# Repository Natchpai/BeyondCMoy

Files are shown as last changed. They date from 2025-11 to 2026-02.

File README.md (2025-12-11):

# BeyondCMoy

**Headphone Amplifier**

> Upgrade NORMAL Headphone Amplifier that my old classwork to something new.

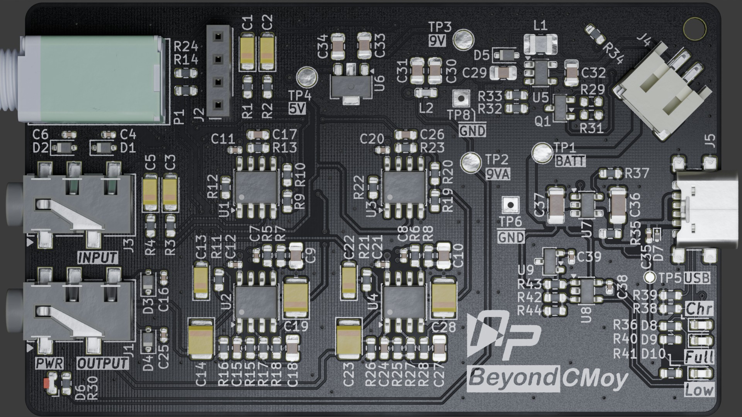
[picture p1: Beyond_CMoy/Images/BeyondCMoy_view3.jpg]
3D


## ✨ Features
- **Inputs:** Bluetooth and 3.5mm Aux jack
- **Battery:** Lithium polymer
- **Charging:** Via USB-C

## 📄 License

This project is licensed under the MIT License. See the [LICENSE](LICENSE) file for details.

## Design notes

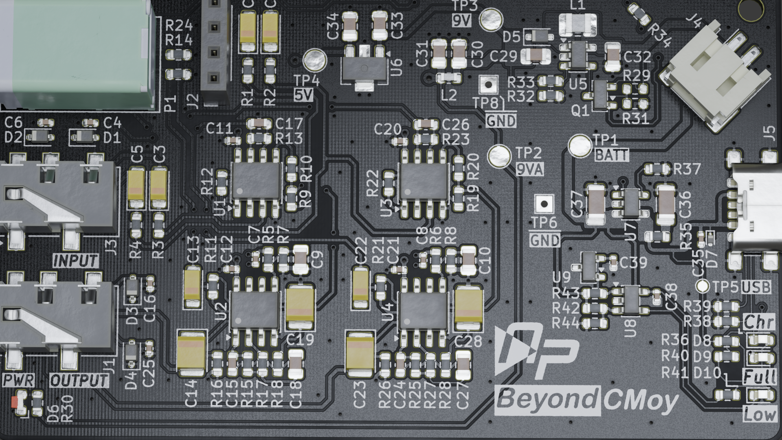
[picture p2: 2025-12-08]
Beyond_CMoy/Images/BeyondCMoy_view2.png

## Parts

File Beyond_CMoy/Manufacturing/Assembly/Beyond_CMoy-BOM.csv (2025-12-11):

# | Reference | Qty | Value | DNP | Exclude from BOM | Exclude from Board | Footprint | Manufacturer | Mf. Part Number | Datasheet | Description
1 | C1,C2,C3,C5,C13,C22 | 6 | 1u |  |  |  | Capacitor_Tantalum_SMD:CP_EIA-3216-18_Kemet-A | KYOCERA AVX | TAJA105M016RNJ |  | Tantalum Chip Capacitors 1μF/16Vdc, ±20%
2 | C14,C23 | 2 | 47u |  |  |  | Capacitor_Tantalum_SMD:CP_EIA-3528-21_Kemet-B | KYOCERA AVX | TAJB476K010RNJ | ~ | Tantalum Chip Capacitors 47μF/10Vdc, ±10%
3 | C15,C17,C24,C26 | 4 | 1n |  |  |  | Capacitor_SMD:C_0603_1608Metric | murata | GRM1885C2A102JA01J | ~ | 1nF/100Vdc, ±5%, C0G(NP0)
4 | C18,C27 | 2 | 0.22u |  |  |  | 0_Devices:0_C_0805_Edited | murata | GRM188R71E224KA88D | ~ | 0.22μF/25Vdc, ±10%, C0G(NP0)
5 | C19,C28 | 2 | 4.7u |  |  |  | Capacitor_Tantalum_SMD:CP_EIA-3528-21_Kemet-B | KYOCERA AVX | TAJB475K016RNJ |  | Tantalum Chip Capacitors 4.7μF/16Vdc, ±10%
6 | C36,C37 | 2 | 10u |  |  |  | Capacitor_SMD:C_1206_3216Metric | SAMSUNG | CL31A106KBHNNNE | ~ | Multilayer Ceramic Chip Cap, 10μF/50Vdc, ±10%, X5R
7 | C4,C6,C16,C25,C35 | 5 | 33p |  |  |  | Capacitor_SMD:C_0402_1005Metric | KYOCERA AVX | 04025A330JAT2A | ~ | 33pF/50Vdc ±5%, C0G(NP0)
8 | C7,C8,C11,C12,C20,C21,C38,C39 | 8 | 0.1u |  |  |  | Capacitor_SMD:C_0402_1005Metric | murata | GRM155R71H104KE14D | ~ | 0.1μF/50Vdc, ±10%, X7R
9 | C9,C10,C29,C30,C31,C32,C33,C34 | 8 | 1u |  |  |  | 0_Devices:0_C_0805_Edited | SAMSUNG | CL21B105KBFNNNE | ~ | 1μF/50Vdc, ±10%, X7R
10 | D5 | 1 | RB551VM-30 |  |  |  | Diode_SMD:D_SOD-323F | ROHM | RB551VM-30TE-17 | ~ | Schottky Barrier Single Diode 30V/500mA
11 | D6 | 1 | GREEN |  |  |  | LED_SMD:LED_Kingbright_APA1606_1.6x0.6mm_Horizontal | LITE-ON | LTST-S270KGKT | ~ | Light emitting diode
12 | D7 | 1 | ESD9L5.0ST5G |  |  |  | Diode_SMD:D_SOD-923 | ONSEMI | ESD9L5.0ST5G |  | ESD Protection Diode
13 | D8 | 1 | ORANGE |  |  |  | LED_SMD:LED_0603_1608Metric | ROHM | SML-D12D8WT86R | ~ | Light emitting diode
14 | D9 | 1 | GREEN |  |  |  | LED_SMD:LED_0603_1608Metric | LITE-ON | LTST-C191TGKT | ~ | Light emitting diode
15 | D10 | 1 | RED |  |  |  | LED_SMD:LED_0603_1608Metric | LITE-ON | LTST-C191KRKT | ~ | Super Thin Chip LED, Red Color
16 | D1,D2,D3,D4 | 4 | PESD12VL1BA |  |  |  | Diode_SMD:D_SOD-323 | NXP | PESD12VL1BA |  | ESD protection diode, 200W,Breakdown Voltage 15.9V
17 | J2 | 1 | Conn_01x04_Socket |  |  |  | Connector_PinSocket_2.54mm:PinSocket_1x04_P2.54mm_Vertical | - | - | ~ | 1x04 Female PinSocket
18 | J4 | 1 | Conn_01x02_MountingPin |  |  |  | Connector_JST:JST_PH_S2B-PH-SM4-TB_1x02-1MP_P2.00mm_Horizontal | JST | S2B-PH-SM4-TB | ~ | 1x02 JST-PH Connector
19 | J5 | 1 | USB_C_Receptacle_PowerOnly_6P |  |  |  | Connector_USB:USB_C_Receptacle_GCT_USB4135-GF-A_6P_TopMnt_Horizontal | SZGOZIE | TYPEC6P019 | https://www.usb.org/sites/default/files/documents/usb_type-c.zip | USB Power-Only 6P Type-C Receptacle connector
20 | J1,J3 | 2 | PJ-327F |  |  |  | 0_AudioConnectors:PJ-327F_SMD | - | PJ-327F | kicad-embed://C128989-PJ-327F.pdf | Auido Jack
21 | L1 | 1 | 10u |  |  |  | 0_Devices:0_L_1008_Edited | murata | DFE252010F-100M=P2 | ~ | Chip Metal Alloy Inductor 10μH ±20%
22 | L2 | 1 | 56n |  |  |  | Inductor_SMD:L_0603_1608Metric | murata | LQW18AN56NG00D | ~ | RF Inductor (Chip Coil), 56nH ±2%, 360mA
23 | P1 | 1 | 10k |  |  |  | 0_Potentiometer:0_RK097GS_Dual_Horizontal_Switch | - | RK097GS |  | 8-Pin Potentiometer 2 Gangs and Switch
24 | Q1 | 1 | MMBT3906 |  |  |  | Package_TO_SOT_SMD:SOT-23 | DIOTEC | MMBT3906 | https://www.onsemi.com/pdf/datasheet/pzt3906-d.pdf | -0.2A Ic, -40V Vce, Small Signal PNP Transistor, SOT-23
25 | R29 | 1 | 0 | DNP |  |  | Resistor_SMD:R_0603_1608Metric | ROYALOHM | 0603WAF0000T5E | ~ | Resistor
26 | R31 | 1 | 10k | DNP |  |  | Resistor_SMD:R_0603_1608Metric | ROYALOHM | 0603WAF1002T5E | ~ | Resistor
27 | R35 | 1 | 1 |  |  |  | Resistor_SMD:R_0603_1608Metric | ROYALOHM | 0603WAF100KT5E | ~ | Resistor
28 | R1,R2,R3,R4,R32,R43 | 6 | 10k |  |  |  | Resistor_SMD:R_0603_1608Metric | ROYALOHM | 0603WAF1002T5E | ~ | Resistor
29 | R12,R16,R22,R26 | 4 | 1k |  |  |  | Resistor_SMD:R_0603_1608Metric | ROHM | MCR03ERTF1001 | ~ | Resistor
30 | R13,R14,R18,R23,R24,R28,R36,R40,R41 | 9 | 2k |  |  |  | Resistor_SMD:R_0603_1608Metric | ROYALOHM | 0603WAF2001T5E | ~ | Resistor
31 | R15,R17,R25,R27,R30,R34,R37,R38,R39 | 9 | 5.1k |  |  |  | Resistor_SMD:R_0603_1608Metric | ROYALOHM | 0603WAF5101T5E | ~ | Resistor
32 | R33,R44 | 2 | 62k |  |  |  | Resistor_SMD:R_0603_1608Metric | ROYALOHM | 0603WAF6202T5E | ~ | Resistor
33 | R5,R6,R7,R8,R9,R10,R11,R19,R20,R21,R42 | 11 | 100k |  |  |  | Resistor_SMD:R_0603_1608Metric | ROYALOHM | 0603WAF1003T5E | ~ | Resistor
34 | TP1 | 1 | +BATT |  | Excluded from BOM |  | TestPoint:TestPoint_Pad_D2.0mm |  |  | ~ | test point
35 | TP2 | 1 | +9VA |  | Excluded from BOM |  | TestPoint:TestPoint_Pad_D2.0mm |  |  | ~ | test point
36 | TP3 | 1 | +9V |  | Excluded from BOM |  | TestPoint:TestPoint_Pad_D2.0mm |  |  | ~ | test point
37 | TP4 | 1 | +5V |  | Excluded from BOM |  | TestPoint:TestPoint_Pad_D2.0mm |  |  | ~ | test point
38 | TP5 | 1 | BUS |  | Excluded from BOM |  | TestPoint:TestPoint_Pad_D1.0mm |  |  | ~ | test point
39 | TP6,TP8 | 2 | GND |  | Excluded from BOM |  | TestPoint:TestPoint_THTPad_1.5x1.5mm_Drill0.7mm |  |  | ~ | test point
40 | U5 | 1 | AP3012 |  |  |  | Package_TO_SOT_SMD:SOT-23-5 | DIODES | AP3012KTR-E1 | https://www.diodes.com/assets/Datasheets/AP3012.pdf | 500mA, Adjustable Step-Up Voltage Regulator, 1.5MHz Frequency, SOT-23-5
41 | U6 | 1 | BD50FA1FP3 |  |  |  | Package_TO_SOT_SMD:SOT-89-3 | ROHM | BD50FA1FP3-ZTL | https://fscdn.rohm.com/en/products/databook/datasheet/ic/power/linear_regulator/bdxxfa1fp3-e.pdf | LDO Regulator Fixed Output 5V/100mA
42 | U7 | 1 | LP4054HB5F |  |  |  | Package_TO_SOT_SMD:SOT-23-5 | LPS | LP4054H | https://lcsc.com/product-detail/PMIC-Battery-Management_LOWPOWER-LP4054HB5F_C517187.html | 600mA Standalone Linear Li-ion Battery Charger
43 | U8 | 1 | BA8391G-TR |  |  |  | Package_TO_SOT_SMD:SOT-23-5 | ROHM | BA8391G-TR |  | Ground Sense Comparator,Open Collector
44 | U9 | 1 | TL432ASF |  |  |  | Package_TO_SOT_SMD:SOT-23 | HTC | TL432ASF | http://www.ti.com/lit/ds/symlink/tl431.pdf | Shunt Regulator, SOT-23
45 | U1,U2,U3,U4 | 4 | NE5532 |  |  |  | Package_SO:SOIC-8_3.9x4.9mm_P1.27mm | - | NE5532 | http://www.ti.com/lit/ds/symlink/ne5532.pdf | Dual Low-Noise Operational Amplifiers, DIP-8/SOIC-8

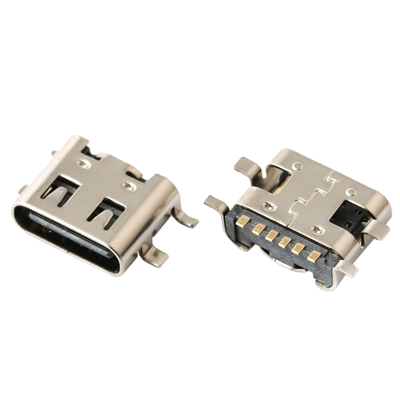
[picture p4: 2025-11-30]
Beyond_CMoy/Images/Components/TYPEC6P019.png

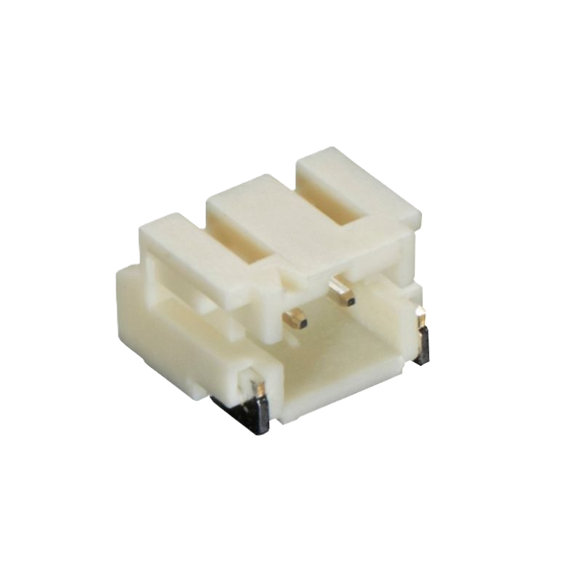
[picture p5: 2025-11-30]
Beyond_CMoy/Images/Components/jst-ph-2-broches-smd-angle-droit.png

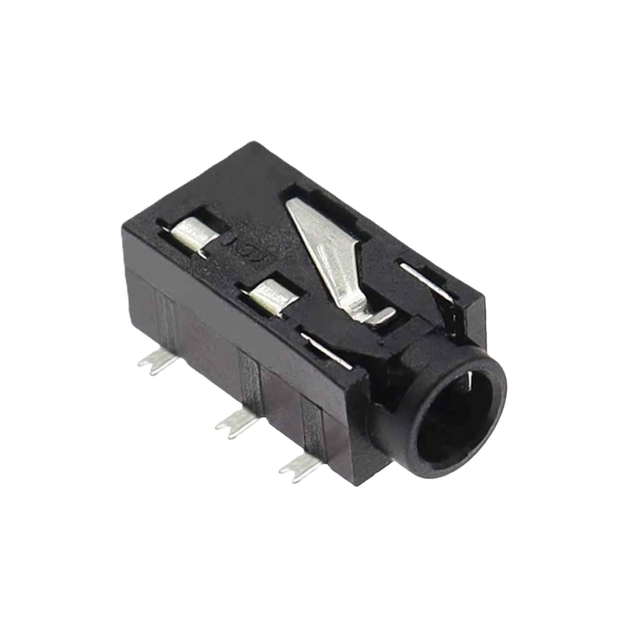
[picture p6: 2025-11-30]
Beyond_CMoy/Images/Components/PJ_327F.png

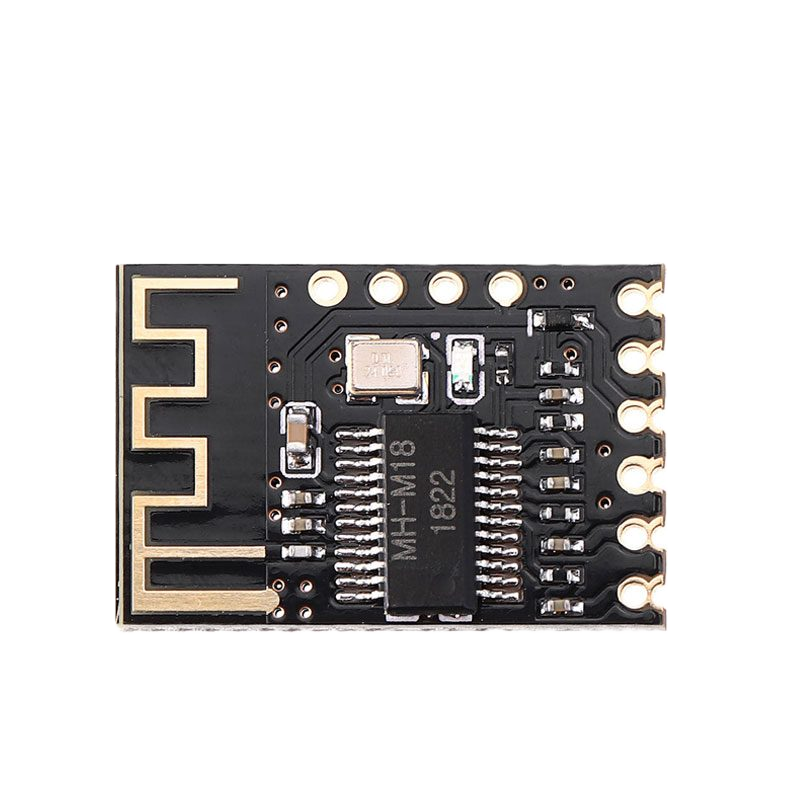
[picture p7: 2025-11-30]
Beyond_CMoy/Images/Components/MH-M18.png

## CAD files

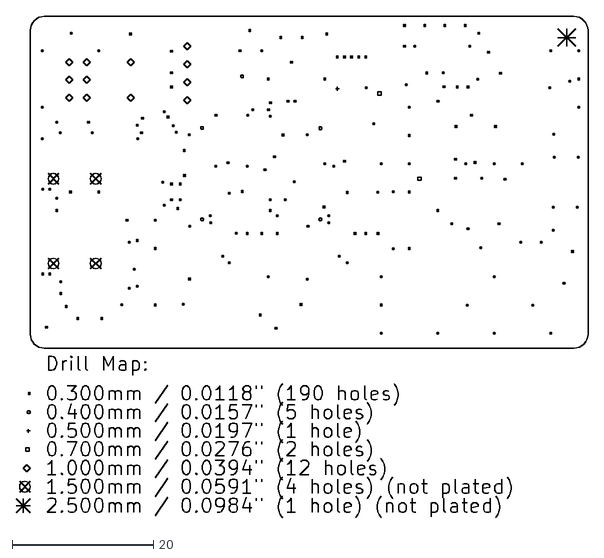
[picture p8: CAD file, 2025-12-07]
Beyond_CMoy/Manufacturing/Fabrication/Beyond_CMoy-drl_map.dxf
81.0 x 71.0

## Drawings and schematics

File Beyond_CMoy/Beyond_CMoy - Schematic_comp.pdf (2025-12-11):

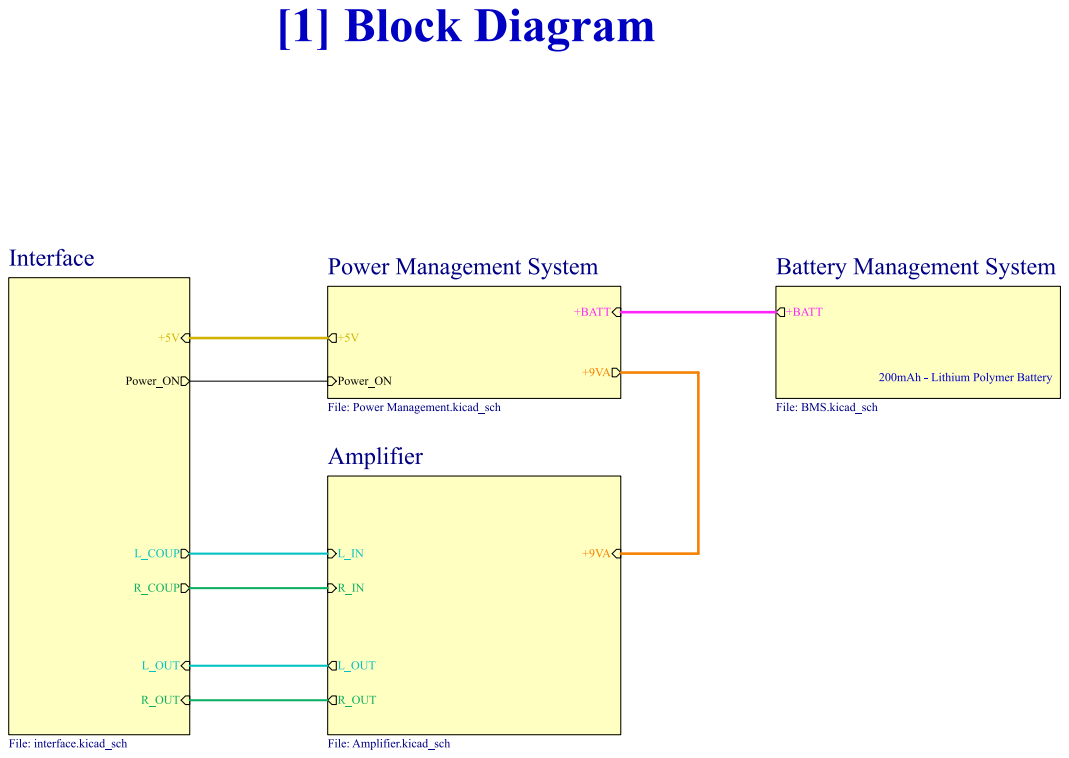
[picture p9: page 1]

Reviewedby NatchanonT. | 6/12/2025

File Beyond_CMoy.kicad_sch

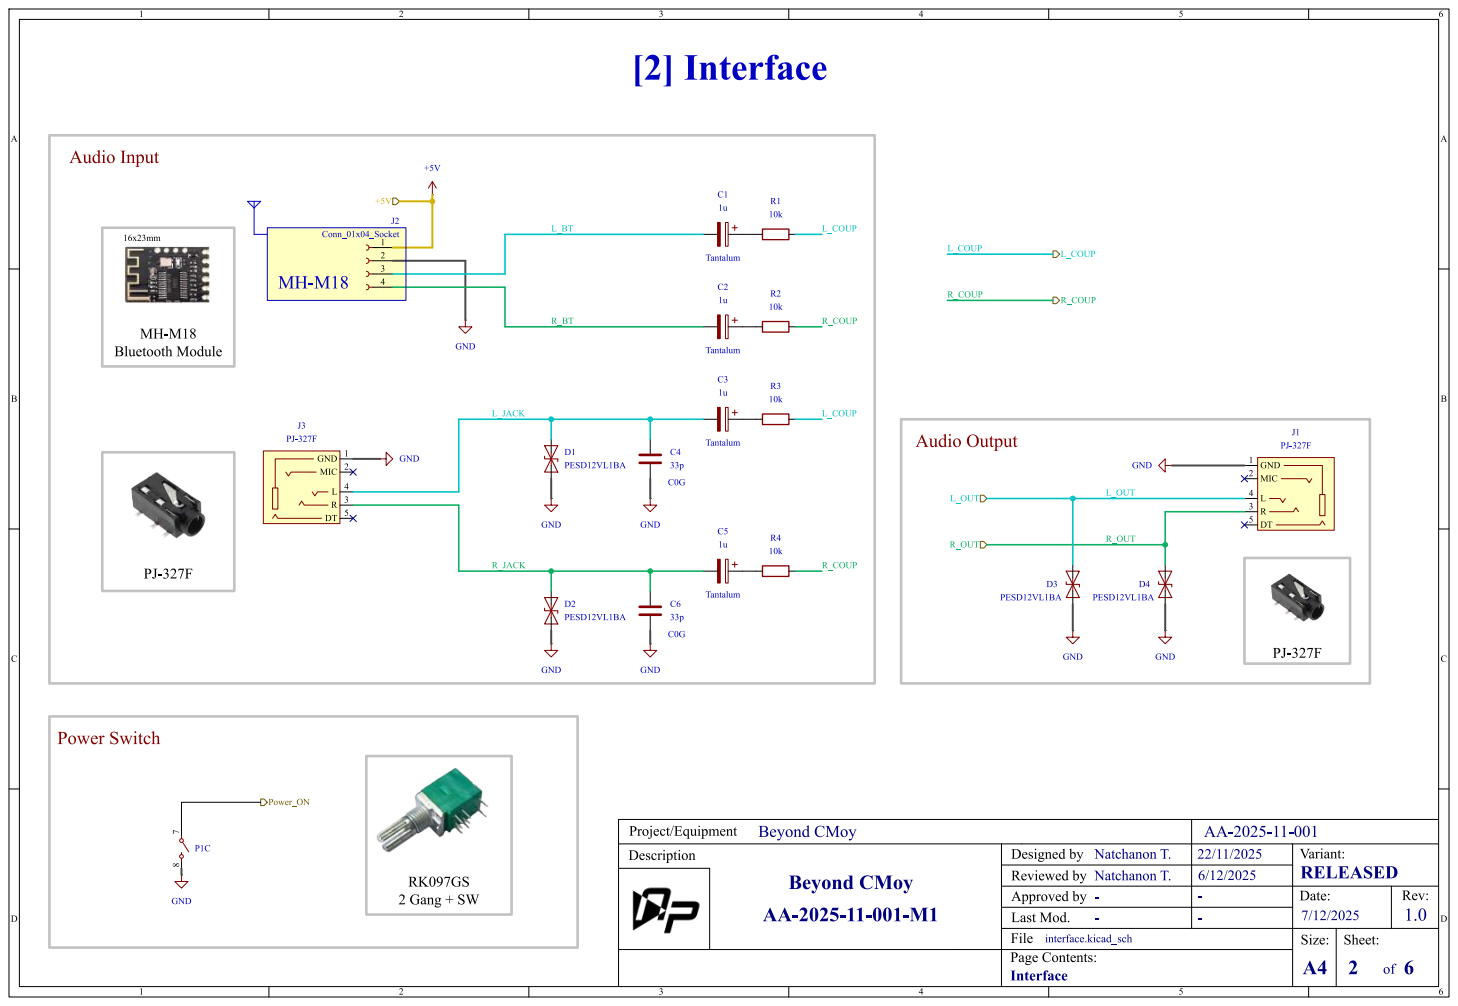
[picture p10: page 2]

PowerSwitch

Reviewedby NatchanonT. | 6/12/2025

File interface.kicad_sch

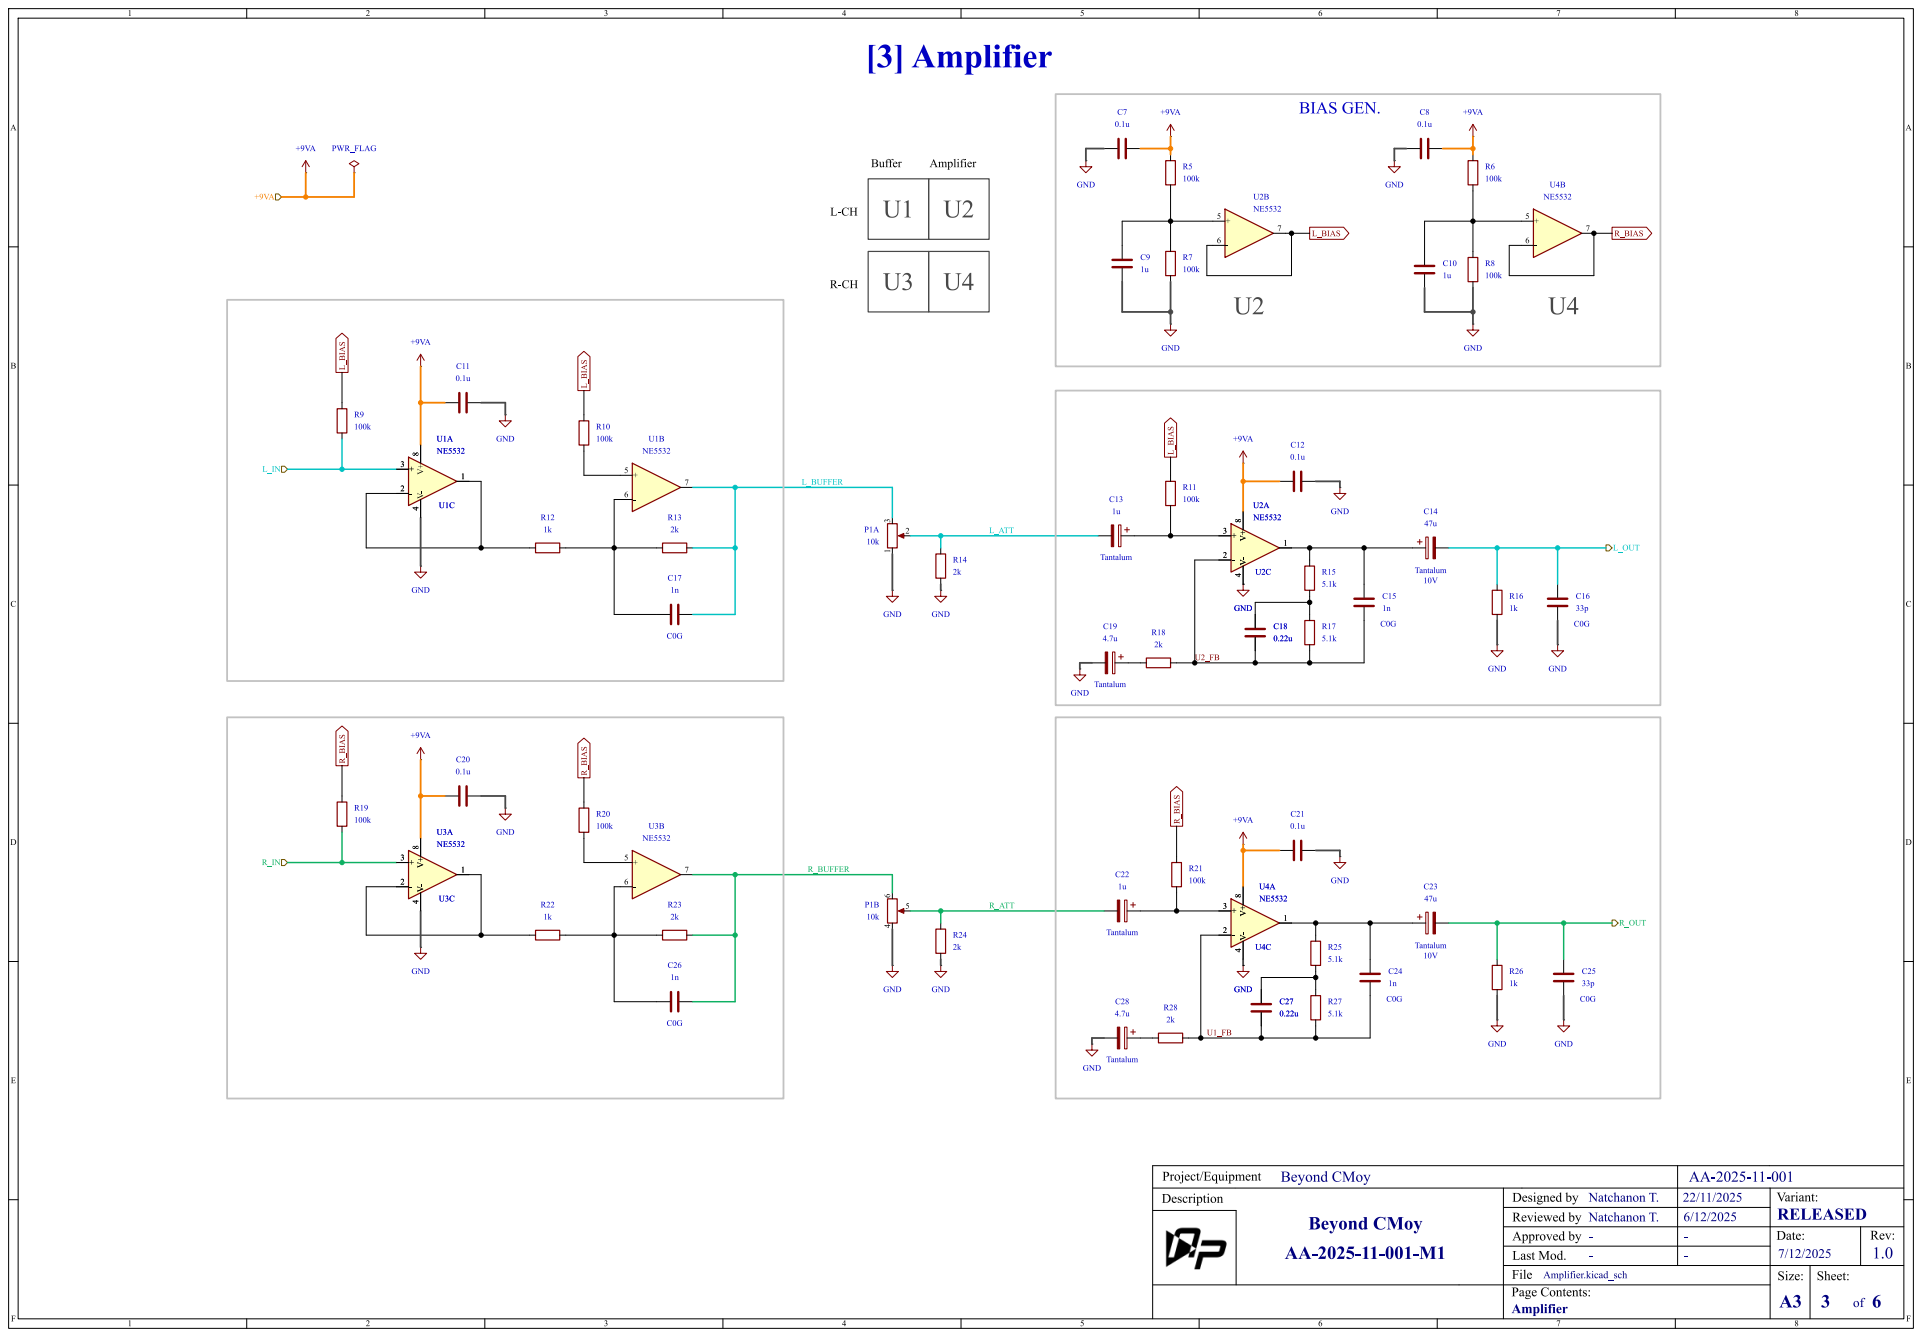
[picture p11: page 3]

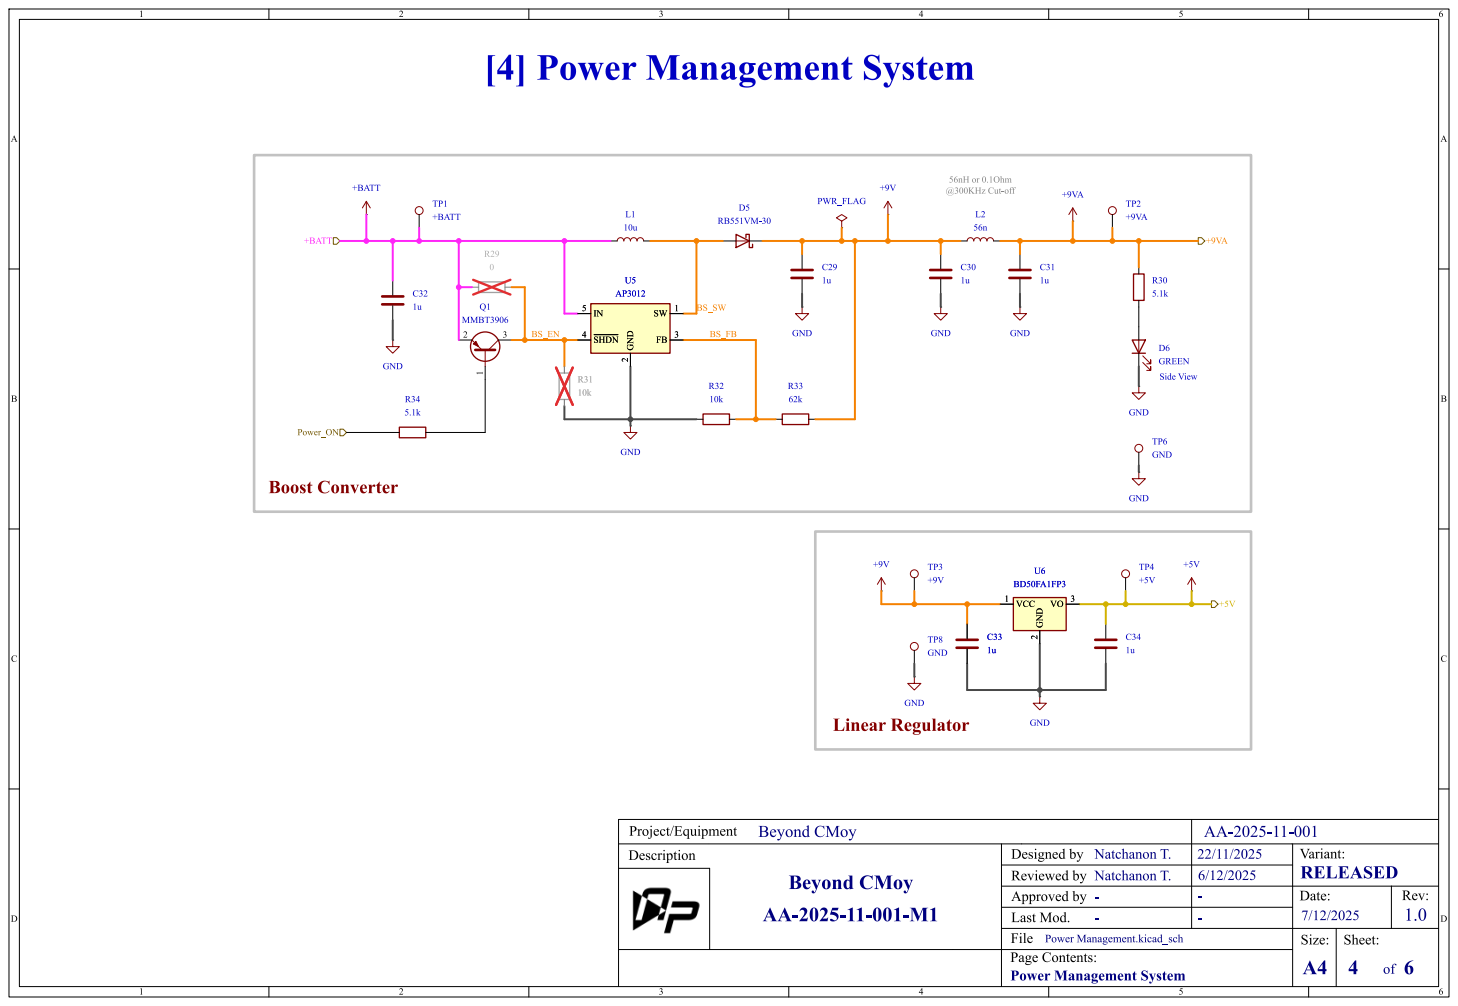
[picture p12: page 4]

Reviewedby NatchanonT. | 6/12/2025

File PowerManagement.kicad_sch

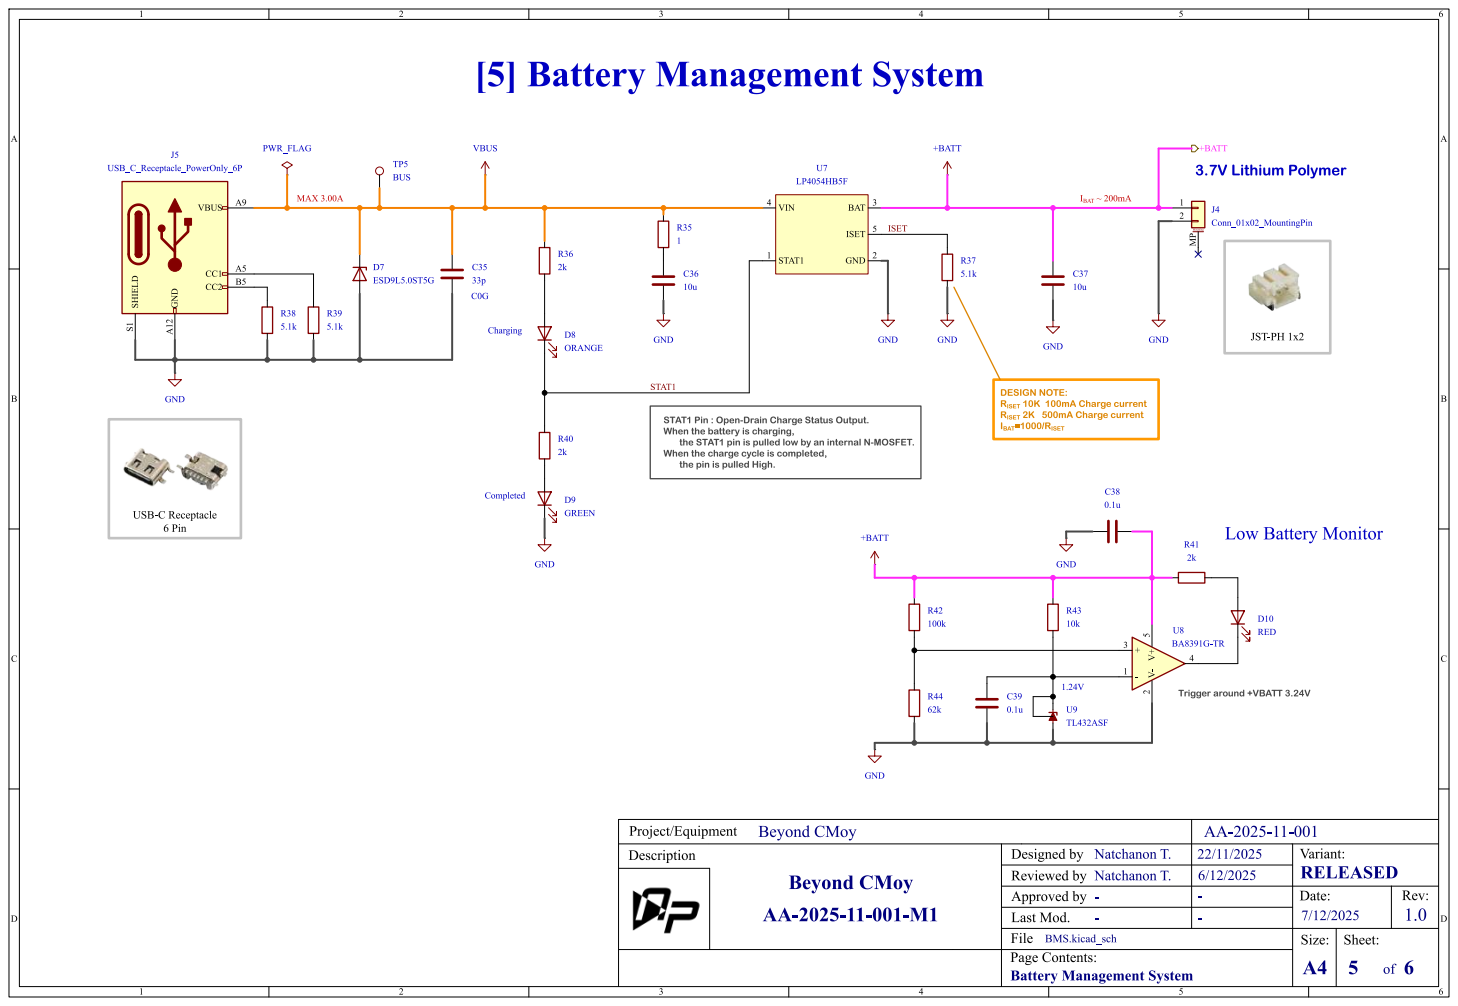
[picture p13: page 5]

Reviewedby NatchanonT. | 6/12/2025

File BMS.kicad_sch

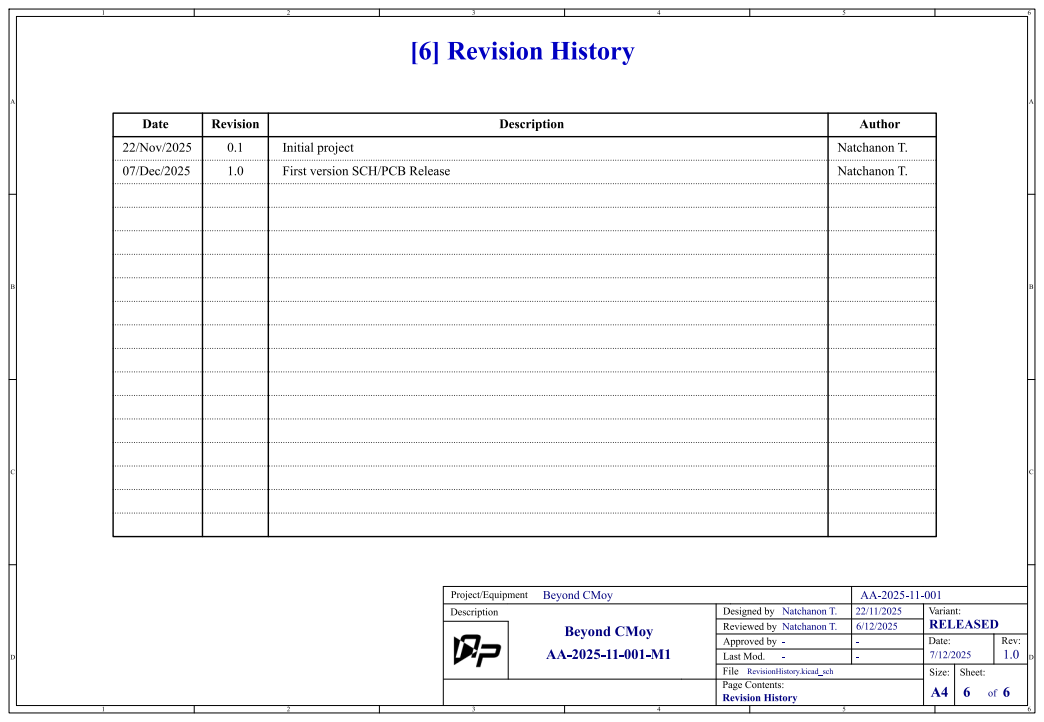
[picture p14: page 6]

Date | Revision | Description | Author
22/Nov/2025 | 0.1 | Initial project | NatchanonT.
07/Dec/2025 | 1.0 | First versionSCH/PCBRelease | NatchanonT.

Reviewedby NatchanonT. | 6/12/2025

File RevisionHistory.kicad_sch

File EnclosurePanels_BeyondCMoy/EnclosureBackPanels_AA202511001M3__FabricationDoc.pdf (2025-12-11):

# BackPanelFabricationDocument

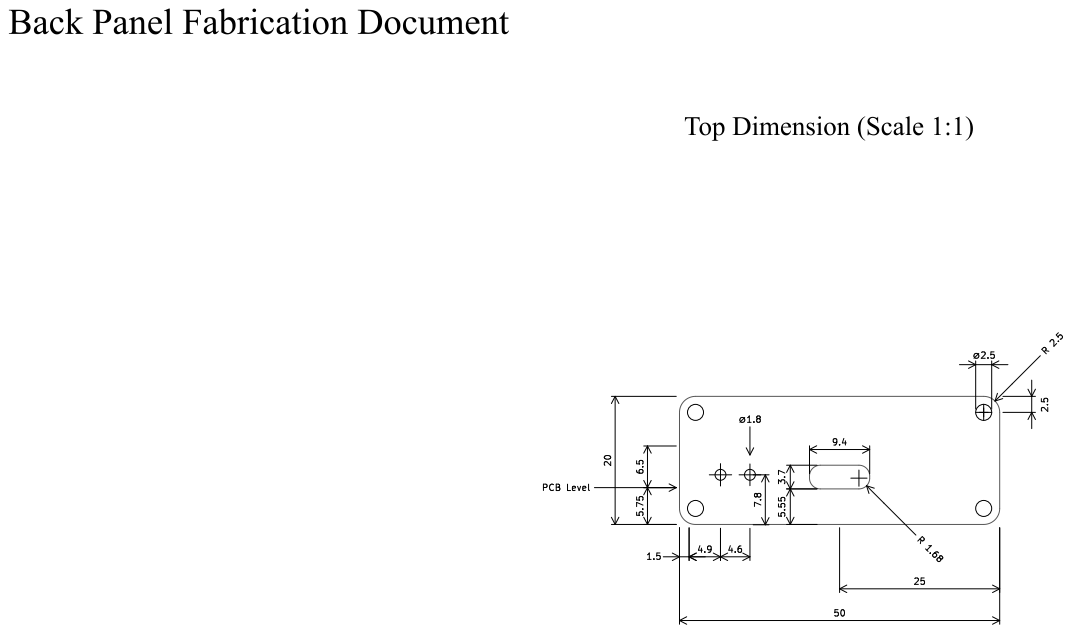
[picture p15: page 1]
þÿ#1.8 PCB Level; D Rev: 1.0; EnclosureBackPanels_AA202511001M3.kicad_pcb; Description; Variant:; Project/Equipment; BackPanel; FabricationDocument; PageContents:; BeyondCMoy; Size:; Sheet:; RELEASED; NatchanonT.; Designedby; LastMod.; - Approvedby -; Date:; ${PROJECT_ID}

Reviewedby NatchanonT. | 7/12/2025

File

# BackPanelFabricationDocument

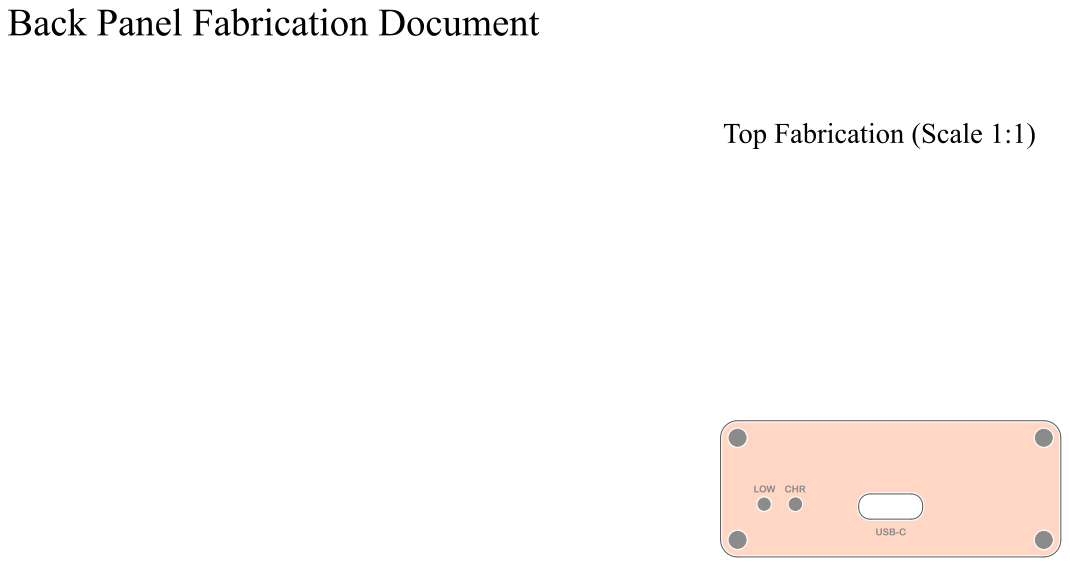
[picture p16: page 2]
D Rev: 1.0; EnclosureBackPanels_AA202511001M3.kicad_pcb; Description; Variant:; Project/Equipment; BackPanel; BeyondCMoy; Size:; Sheet:; RELEASED; NatchanonT.; Designedby; LastMod.; - Approvedby -; Date:; ${PROJECT_ID}

Reviewedby NatchanonT. | 7/12/2025

File

# BackPanelFabricationDocument

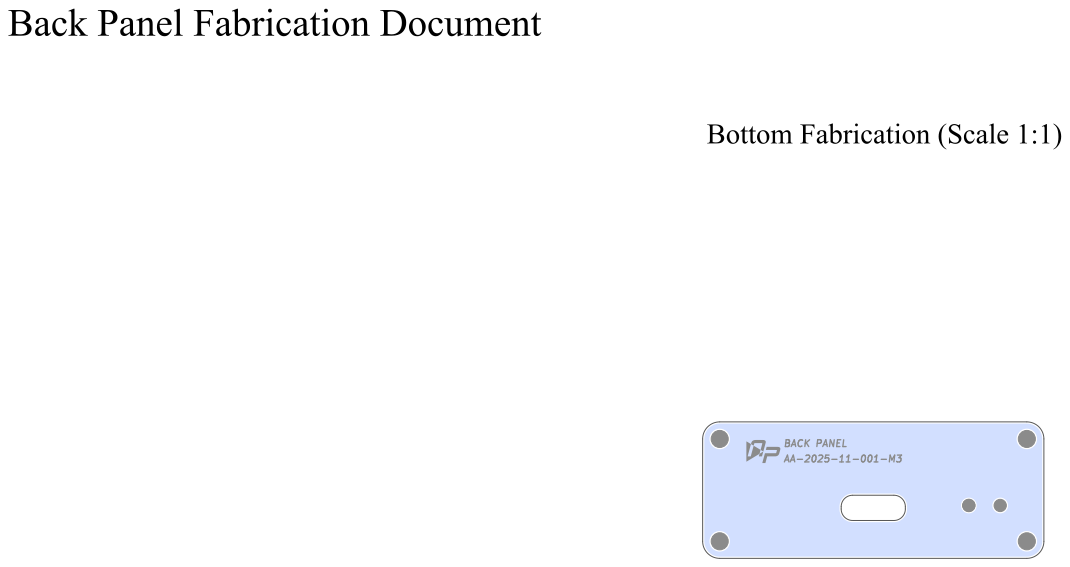
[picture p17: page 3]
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

AA-2025-11-001-M3 BACK PANEL

Reviewedby NatchanonT. | 7/12/2025

File

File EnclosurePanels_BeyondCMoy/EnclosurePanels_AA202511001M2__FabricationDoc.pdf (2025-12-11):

# FrontPanelFabricationDocument

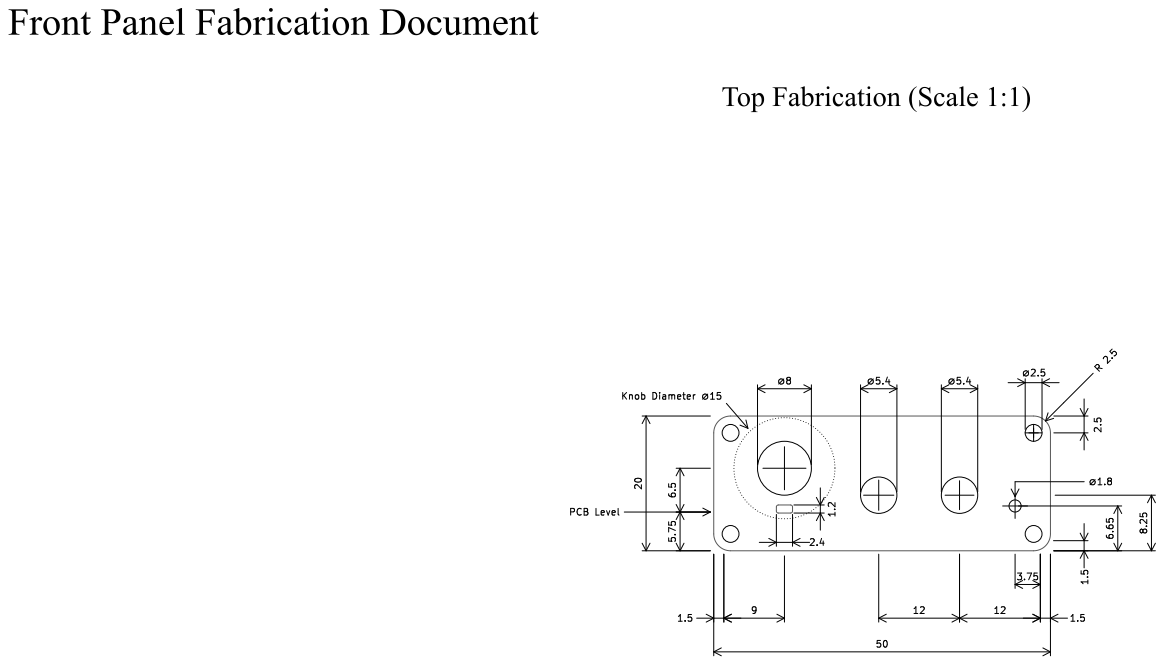
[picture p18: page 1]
þÿ#1.8 Knob Diameter; þÿ#15 PCB Level; D Rev: 1.0; Description; Variant:; Project/Equipment; FrontPanel; FabricationDocument; PageContents:; BeyondCMoy; Size:; Sheet:; RELEASED; NatchanonT.; Designedby; LastMod.; - Approvedby -; Date:; ${PROJECT_ID}

Reviewedby NatchanonT. | 7/12/2025

File EnclosurePanels_AA202511001M2.kicad_pcb

# FrontPanelFabricationDocument

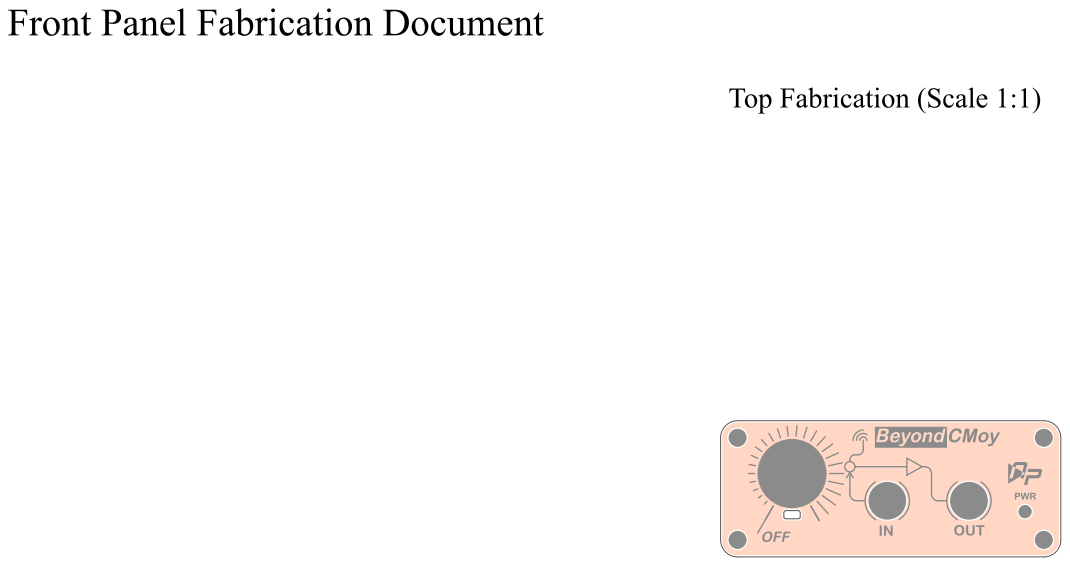
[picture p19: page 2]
D Rev: 1.0; Description; Variant:; Project/Equipment; FrontPanel; BeyondCMoy; Size:; Sheet:; RELEASED; NatchanonT.; Designedby; LastMod.; - Approvedby -; Date:; ${PROJECT_ID}

Reviewedby NatchanonT. | 7/12/2025

File EnclosurePanels_AA202511001M2.kicad_pcb

# FrontPanelFabricationDocument

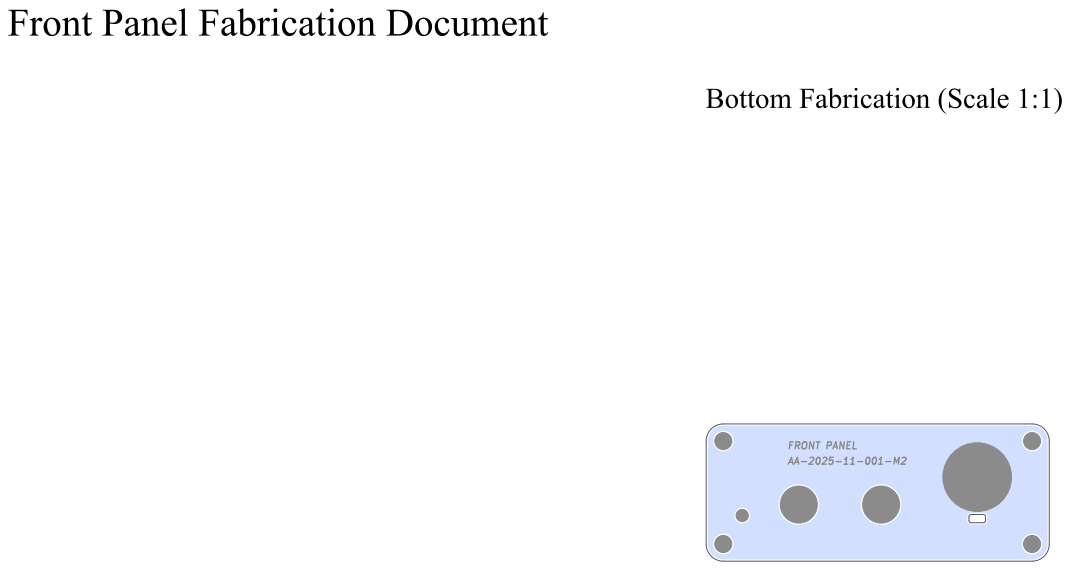
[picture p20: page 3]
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

AA-2025-11-001-M2 FRONT PANEL

Reviewedby NatchanonT. | 7/12/2025

File EnclosurePanels_AA202511001M2.kicad_pcb

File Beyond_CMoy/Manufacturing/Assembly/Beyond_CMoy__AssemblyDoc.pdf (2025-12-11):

# BeyondCMoy AssemblyDocument

D Rev: 1.0; Description; Variant:; Project/Equipment; BeyondCMoy; AssemblyDocument; PageContents:; Size:; Sheet:; RELEASED; NatchanonT.; Designedby; LastMod.; - Approvedby -; Date:; 3D TopBottomView - 1/3

Reviewedby NatchanonT. | 6/12/2025

File Beyond_CMoy.kicad_pcb

# BeyondCMoy AssemblyDocument


# BeyondCMoy AssemblyDocument

Rev1.0 AA-2025-11-001-M1 Amplifier & Li-Po; Battery Charger; D Rev: 1.0; Description; Variant:; Project/Equipment; BeyondCMoy; Size:; Sheet:; RELEASED; NatchanonT.; Designedby; LastMod.; - Approvedby -; Date:; AssemblyBottom - 3/3

Reviewedby NatchanonT. | 6/12/2025

File Beyond_CMoy.kicad_pcb

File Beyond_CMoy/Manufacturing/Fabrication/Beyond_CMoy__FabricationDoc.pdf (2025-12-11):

A

A


Name Edge card connectors:

A

A

D Rev: 1.0; Description; Variant:; Project/Equipment; BeyondCMoy; Size:; Sheet:; RELEASED; NatchanonT.; Designedby; LastMod.; - Approvedby -; Date:; BeyondCMoy AssemblyDocument; DrillMap - 2/5; Plated; 4 Size; Plate Plated Count 1 Symbol; Plated Plated

Non-Plated Plated

Reviewedby NatchanonT. | 6/12/2025

File Beyond_CMoy.kicad_pcb

A

A


A

A

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

Reviewedby NatchanonT. | 6/12/2025

File Beyond_CMoy.kicad_pcb

A

A

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

Reviewedby NatchanonT. | 6/12/2025

File Beyond_CMoy.kicad_pcb

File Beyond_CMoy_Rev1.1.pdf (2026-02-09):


Reviewedby NatchanonT. | 6/12/2025

File Beyond_CMoy.kicad_sch


Reviewedby NatchanonT. | 6/12/2025

File interface.kicad_sch



Reviewedby NatchanonT. | 6/12/2025

File PowerManagement.kicad_sch


Trigger around +VBATT 3.24V [5] BatteryManagementSystem

STAT1 Pin : Open-Drain Charge Status Output. When the battery is charging,

Reviewedby NatchanonT. | 6/12/2025

File BMS.kicad_sch


PowerManagementSystem
* UseMOSFETasa switchto powerup the module. * ChangedBD50FA1FP3(5VRegulator)PinAlignment

Reviewedby NatchanonT. | 6/12/2025

File RevisionHistory.kicad_sch

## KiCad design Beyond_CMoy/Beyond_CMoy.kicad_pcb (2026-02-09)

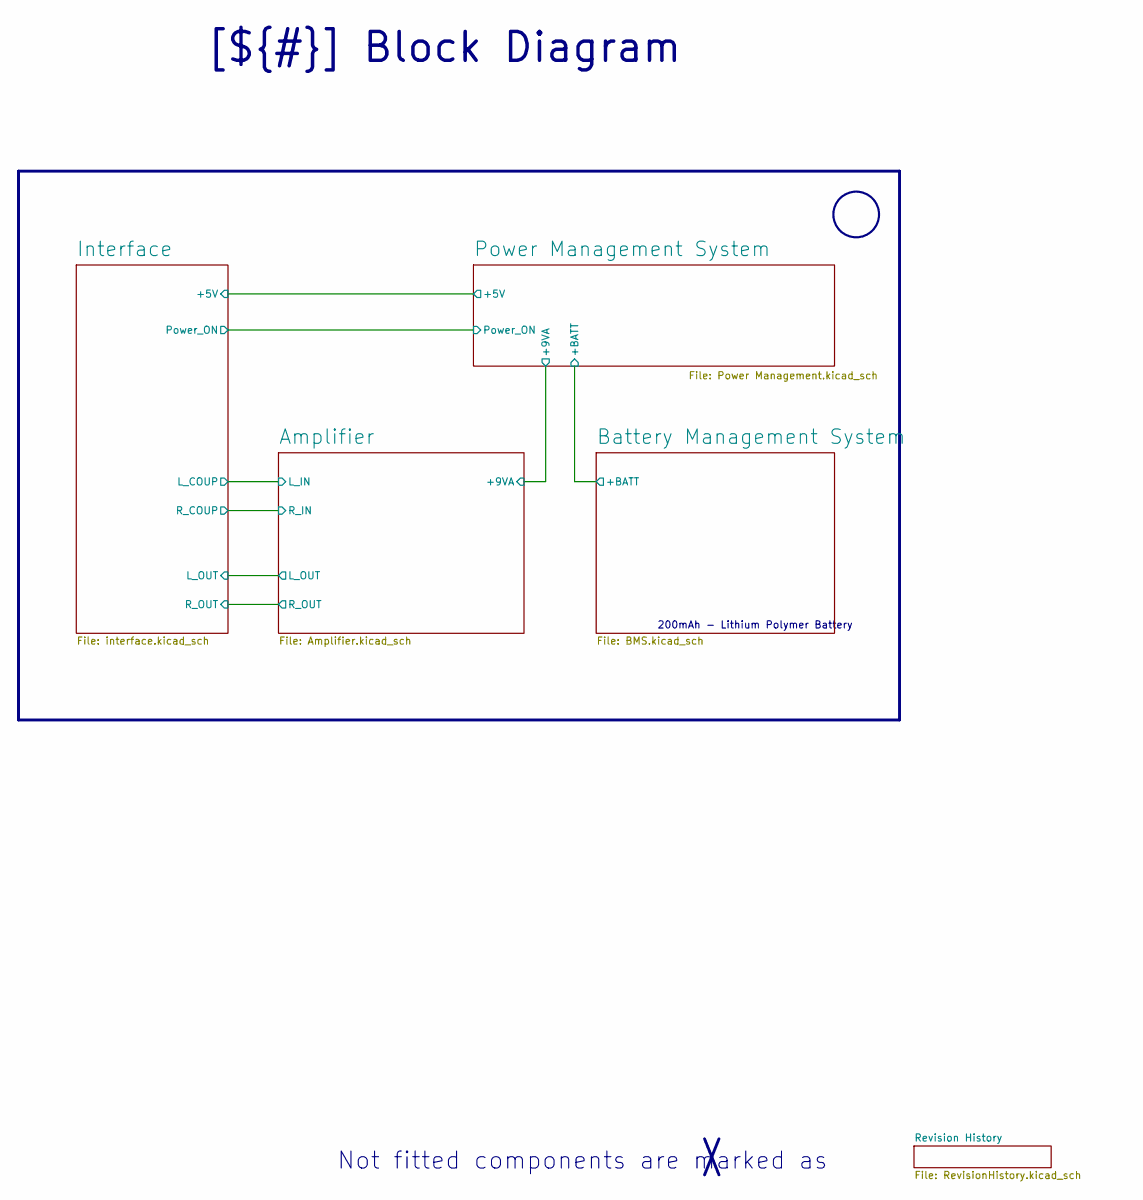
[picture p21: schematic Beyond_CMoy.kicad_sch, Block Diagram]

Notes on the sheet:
[${#}] ${TITLE}
200mAh - Lithium Polymer Battery
Not fitted components are marked as

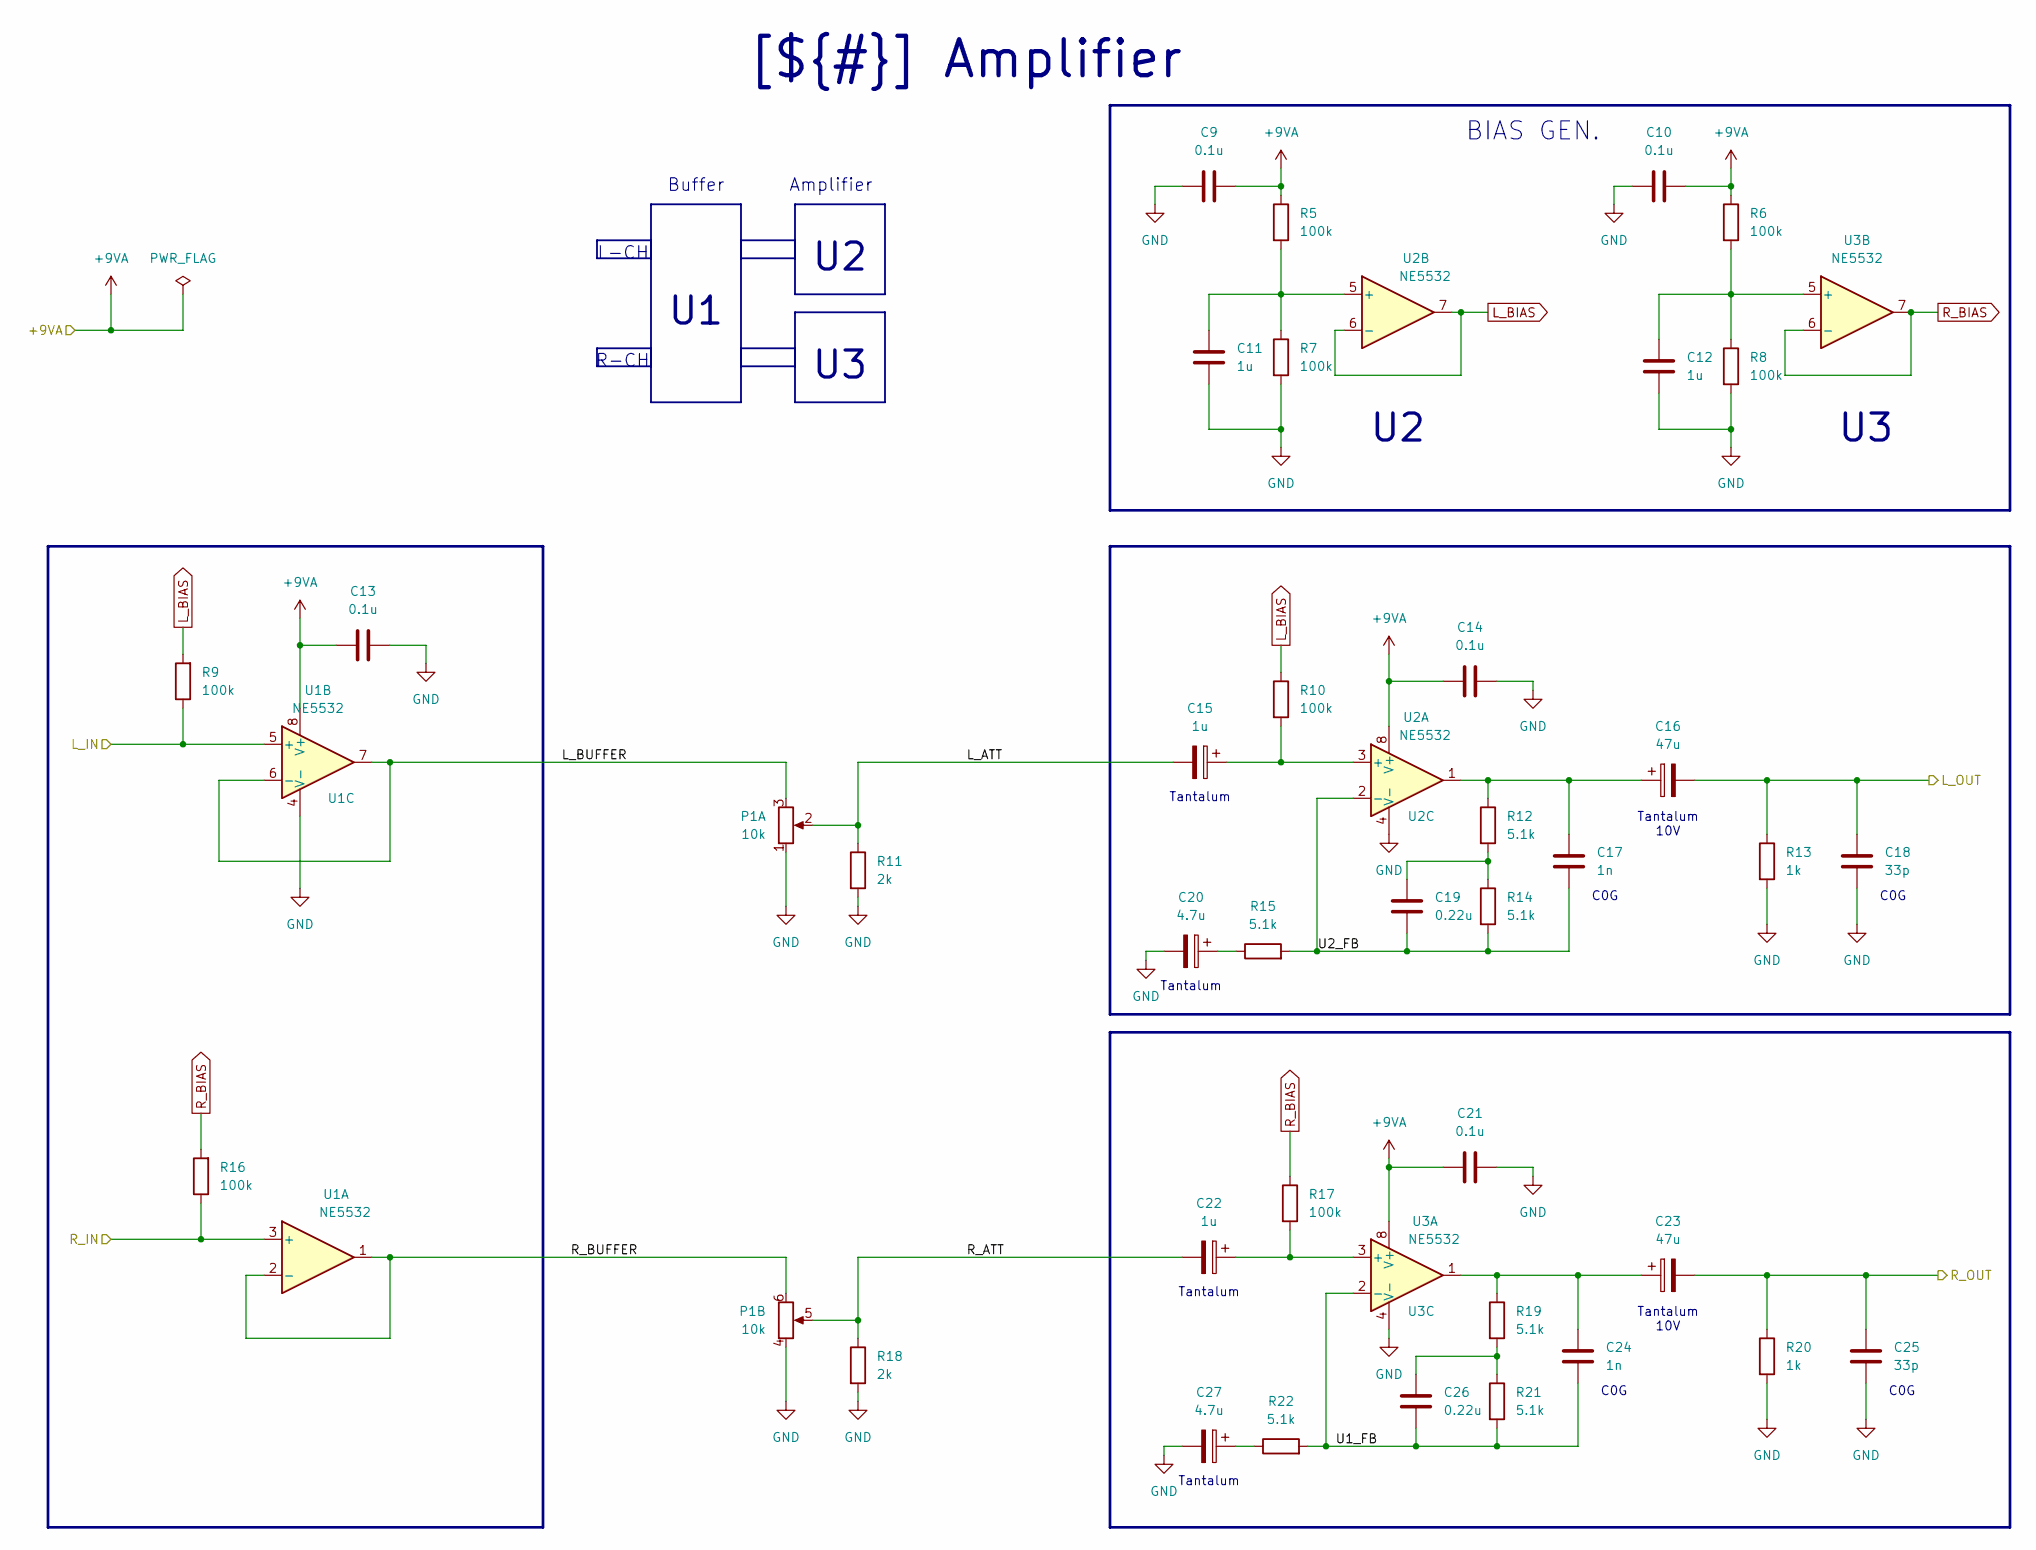
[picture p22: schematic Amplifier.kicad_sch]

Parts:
C9, C10, C13, C14, C21: 0.1u; C_0402_1005Metric; Mf. Part Number GRM155R71H104KE14D
C11, C12: 1u; 0_C_0805_Edited; Mf. Part Number CL21B105KBFNNNE
C15, C22: 1u; CP_EIA-3216-18_Kemet-A; Mf. Part Number TAJA105M016RNJ
C16, C23: 47u; CP_EIA-3528-21_Kemet-B; Mf. Part Number TAJB476K010RNJ
C17, C24: 1n; C_0603_1608Metric; Mf. Part Number GRM1885C2A102JA01J
C18, C25: 33p; C_0402_1005Metric; Mf. Part Number 04025A330JAT2A
C19, C26: 0.22u; C_0603_1608Metric; Mf. Part Number GRM188R71E224KA88D
C20, C27: 4.7u; CP_EIA-3528-21_Kemet-B; Mf. Part Number TAJB475K016RNJ
P1: 10k; 0_RK097GS_Dual_Horizontal_Switch; Mf. Part Number RK097GS
R5, R6, R7, R8, R9, R10, R16, R17: 100k; R_0603_1608Metric; Mf. Part Number 0603WAF1003T5E
R11, R18: 2k; R_0603_1608Metric; Mf. Part Number 0603WAF2001T5E
R12, R14, R19, R21: 5.1k; R_0603_1608Metric; Mf. Part Number 0603WAF5101T5E
R13, R20: 1k; R_0603_1608Metric; Mf. Part Number MCR03ERTF1001
R15, R22: 5.1k; R_0603_1608Metric; Mf. Part Number 0603WAF2001T5E
U1, U2, U3: NE5532; SOIC-8_3.9x4.9mm_P1.27mm; Mf. Part Number NE5532

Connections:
+9VA: C9.2, C10.2, C13.1, C14.1, C21.1, R5.1, R6.1, U1.8 (V+), U2.8 (V+), U3.8 (V+); also elsewhere on the board
/Amplifier/L_ATT: C15.2, P1.2, R11.1
/Amplifier/L_BUFFER: P1.3, U1.6 (-), U1.7
/Amplifier/R_ATT: C22.2, P1.5, R18.1
/Amplifier/R_BUFFER: P1.6, U1.1, U1.2 (-)
/Amplifier/U1_FB: C24.2, C26.2, R21.2, R22.2, U3.2 (-)
/Amplifier/U2_FB: C17.2, C19.2, R14.2, R15.2, U2.2 (-)
/Interface/L_COUP: R9.1, U1.5 (+); also elsewhere on the board
/Interface/L_OUT: C16.2, C18.1, R13.1; also elsewhere on the board
/Interface/R_COUP: R16.1, U1.3 (+); also elsewhere on the board
/Interface/R_OUT: C23.2, C25.1, R20.1; also elsewhere on the board
GND: C9.1, C10.1, C11.2, C12.2, C13.2, C14.2, C18.2, C20.2, C21.2, C25.2, C27.2, P1.1, P1.4, R7.2, R8.2, R11.2, R13.2, R18.2, R20.2, U1.4 (V-), U2.4 (V-), U3.4 (V-); also elsewhere on the board
L_BIAS: R9.2, R10.1, U2.6 (-), U2.7
unnamed: C16.1, C17.1, R12.1, U2.1
unnamed: C19.1, R12.2, R14.1
unnamed: C20.1, R15.1
unnamed: C23.1, C24.1, R19.1, U3.1
unnamed: C26.1, R19.2, R21.1
unnamed: C27.1, R22.1
unnamed: C15.1, R10.2, U2.3 (+)
unnamed: C11.1, R5.2, R7.1, U2.5 (+)
unnamed: C22.1, R17.2, U3.3 (+)
unnamed: C12.1, R6.2, R8.1, U3.5 (+)
R_BIAS: R16.2, R17.1, U3.6 (-), U3.7

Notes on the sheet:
Tantalum
L-CH
C0G
Buffer
Tantalum 10V
R-CH
[${#}] ${TITLE}
Amplifier
BIAS GEN.

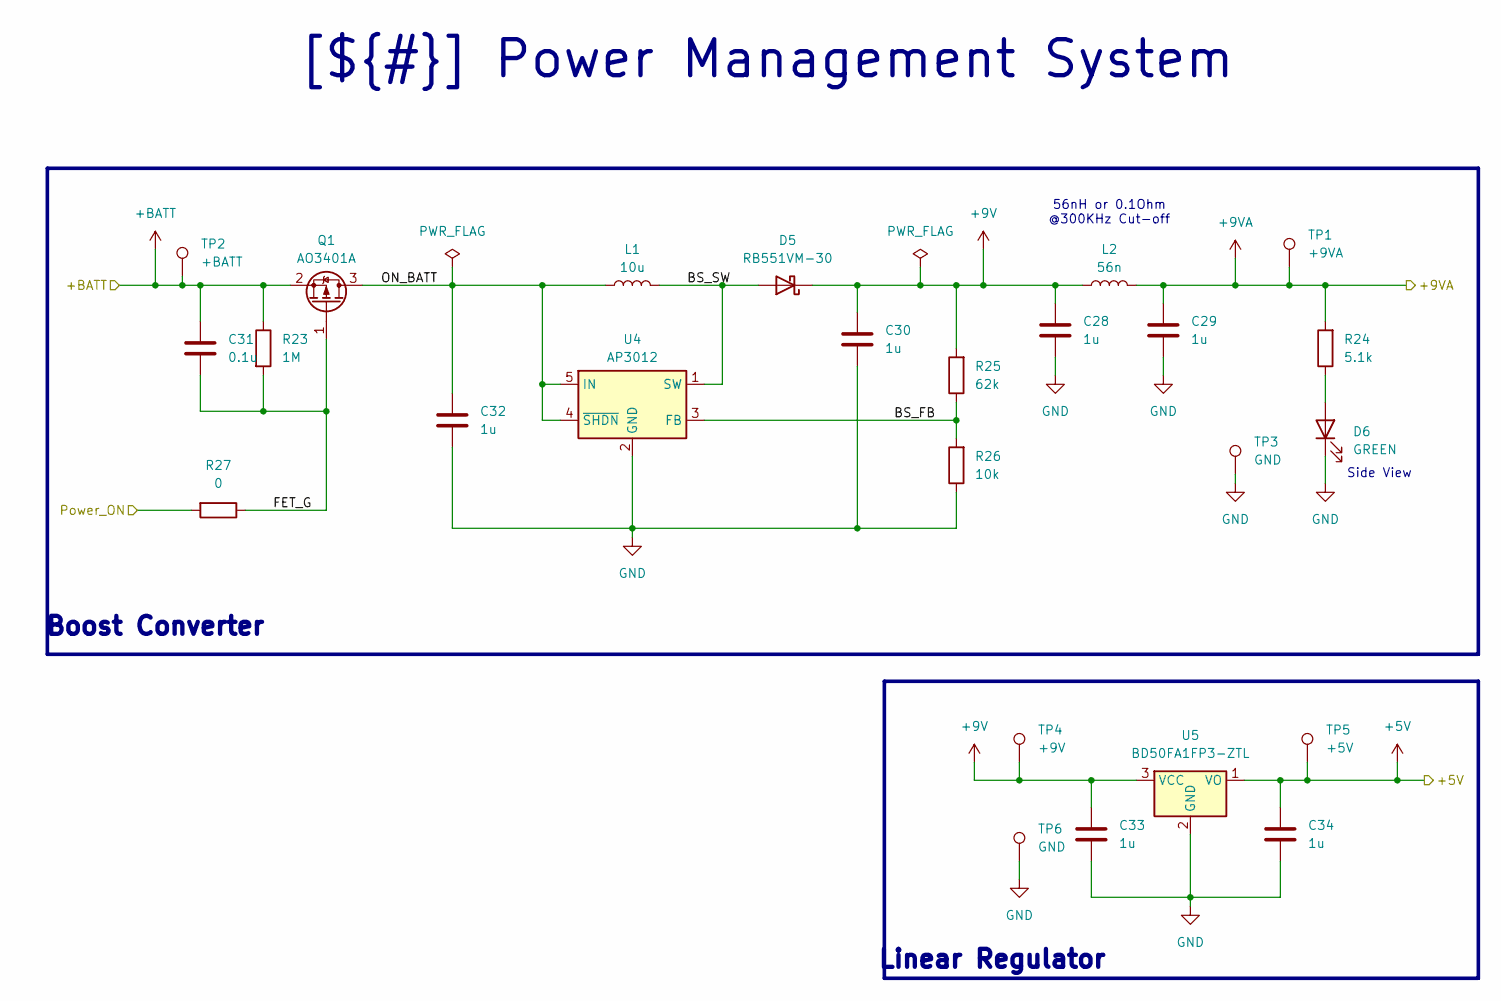
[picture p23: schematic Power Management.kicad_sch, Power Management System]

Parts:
C28, C29, C30, C32, C33, C34: 1u; 0_C_0805_Edited; Mf. Part Number CL21B105KBFNNNE
C31: 0.1u; C_0402_1005Metric; Mf. Part Number GRM155R71H104KE14D
D5: RB551VM-30; D_SOD-323F; Mf. Part Number RB551VM-30TE-17
D6: GREEN; LED_Kingbright_APA1606_1.6x0.6mm_Horizontal; Mf. Part Number LTST-S270KGKT
L1: 10u; 0_L_1008_Edited; Mf. Part Number DFE252010F-100M=P2
L2: 56n; L_0603_1608Metric; Mf. Part Number LQW18AN56NG00D
Q1: AO3401A; SOT-23-3; Mf. Part Number AO3401A
R23: 1M; R_0603_1608Metric; Mf. Part Number 0603WAF0000T5E
R24: 5.1k; R_0603_1608Metric; Mf. Part Number 0603WAF5101T5E
R25: 62k; R_0603_1608Metric; Mf. Part Number 0603WAF6202T5E
R26: 10k; R_0603_1608Metric; Mf. Part Number 0603WAF1002T5E
R27: 0; R_0603_1608Metric; Mf. Part Number 0603WAF5101T5E
TP1: +9VA; TestPoint_Pad_D2.0mm
TP2: +BATT; TestPoint_Pad_D2.0mm
TP3, TP6: GND; TestPoint_THTPad_1.5x1.5mm_Drill0.7mm
TP4: +9V; TestPoint_Pad_D2.0mm
TP5: +5V; TestPoint_Pad_D1.0mm
U4: AP3012; SOT-23-5; Mf. Part Number AP3012KTR-E1
U5: BD50FA1FP3-ZTL; SOT-89-3

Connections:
+5V: C34.1, TP5.1, U5.1 (VO); also elsewhere on the board
+9V: C28.1, C30.1, C33.1, D5.1 (K), L2.1, R25.2, TP4.1, U5.3 (VCC)
+9VA: C29.1, L2.2, R24.2, TP1.1; also elsewhere on the board
+BATT: C31.1, Q1.2 (S), R23.1, TP2.1; also elsewhere on the board
/Interface/Power_ON: R27.2; also elsewhere on the board
/Power Management System/BS_FB: R25.1, R26.2, U4.3 (FB)
/Power Management System/BS_SW: D5.2 (A), L1.2, U4.1 (SW)
/Power Management System/FET_G: C31.2, Q1.1 (G), R23.2, R27.1
/Power Management System/ON_BATT: C32.1, L1.1, Q1.3 (D), U4.4 (~SHDN), U4.5 (IN)
GND: C28.2, C29.2, C30.2, C32.2, C33.2, C34.2, D6.1 (K), R26.1, TP3.1, TP6.1, U4.2 (GND), U5.2 (GND); also elsewhere on the board
unnamed: D6.2 (A), R24.1

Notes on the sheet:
Boost Converter
Linear Regulator
Side View
[${#}] ${TITLE}
56nH or 0.1Ohm @300KHz Cut-off

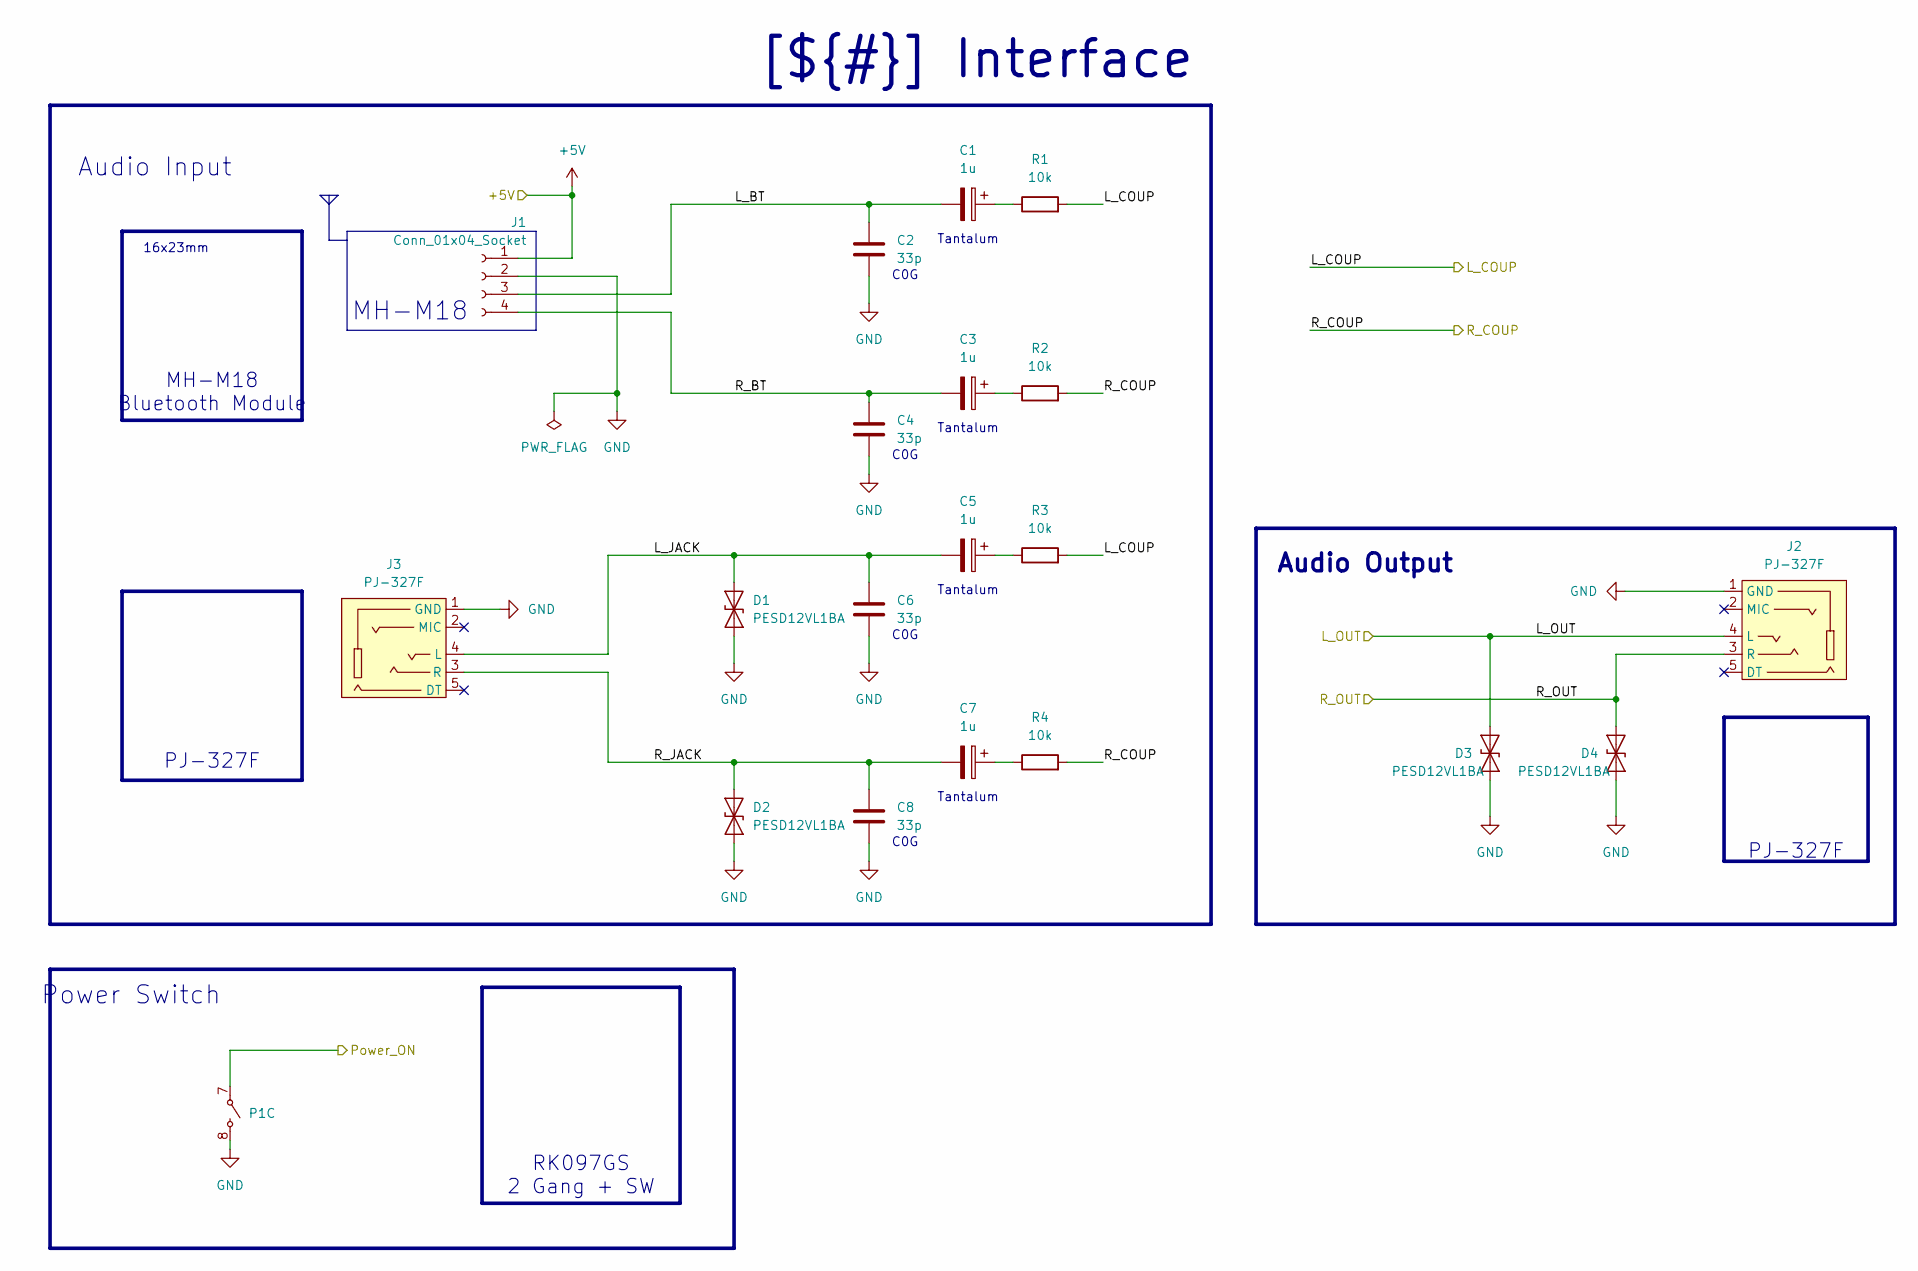
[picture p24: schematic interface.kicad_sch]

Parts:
C1, C3, C5, C7: 1u; CP_EIA-3216-18_Kemet-A; Mf. Part Number TAJA105M016RNJ
C2, C4, C6, C8: 33p; C_0402_1005Metric; Mf. Part Number 04025A330JAT2A
D1, D2, D3, D4: PESD12VL1BA; D_SOD-323; Mf. Part Number PESD12VL1BA
J1: Conn_01x04_Socket; PinSocket_1x04_P2.54mm_Vertical
J2, J3: PJ-327F; PJ-327F_SMD; Mf. Part Number PJ-327F
P1: 10k; 0_RK097GS_Dual_Horizontal_Switch; Mf. Part Number RK097GS
R1, R2, R3, R4: 10k; R_0603_1608Metric; Mf. Part Number 0603WAF1002T5E

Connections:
+5V: J1.1; also elsewhere on the board
/Interface/L_BT: C1.2, C2.1, J1.3
/Interface/L_COUP: R1.2, R3.2; also elsewhere on the board
/Interface/L_JACK: C5.2, C6.1, D1.2 (A2), J3.4 (L)
/Interface/L_OUT: D3.2 (A2), J2.4 (L); also elsewhere on the board
/Interface/Power_ON: P1.7; also elsewhere on the board
/Interface/R_BT: C3.2, C4.1, J1.4
/Interface/R_COUP: R2.2, R4.2; also elsewhere on the board
/Interface/R_JACK: C7.2, C8.1, D2.2 (A2), J3.3 (R)
/Interface/R_OUT: D4.2 (A2), J2.3 (R); also elsewhere on the board
GND: C2.2, C4.2, C6.2, C8.2, D1.1 (A1), D2.1 (A1), D3.1 (A1), D4.1 (A1), J1.2, J2.1 (GND), J3.1 (GND), P1.8; also elsewhere on the board
unnamed: C1.1, R1.1
unnamed: C3.1, R2.1
unnamed: C5.1, R3.1
unnamed: C7.1, R4.1

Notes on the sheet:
Tantalum
C0G
Audio Output
MH-M18
Power Switch
RK097GS 2 Gang + SW
MH-M18 Bluetooth Module
[${#}] ${TITLE}
PJ-327F
16x23mm
Audio Input

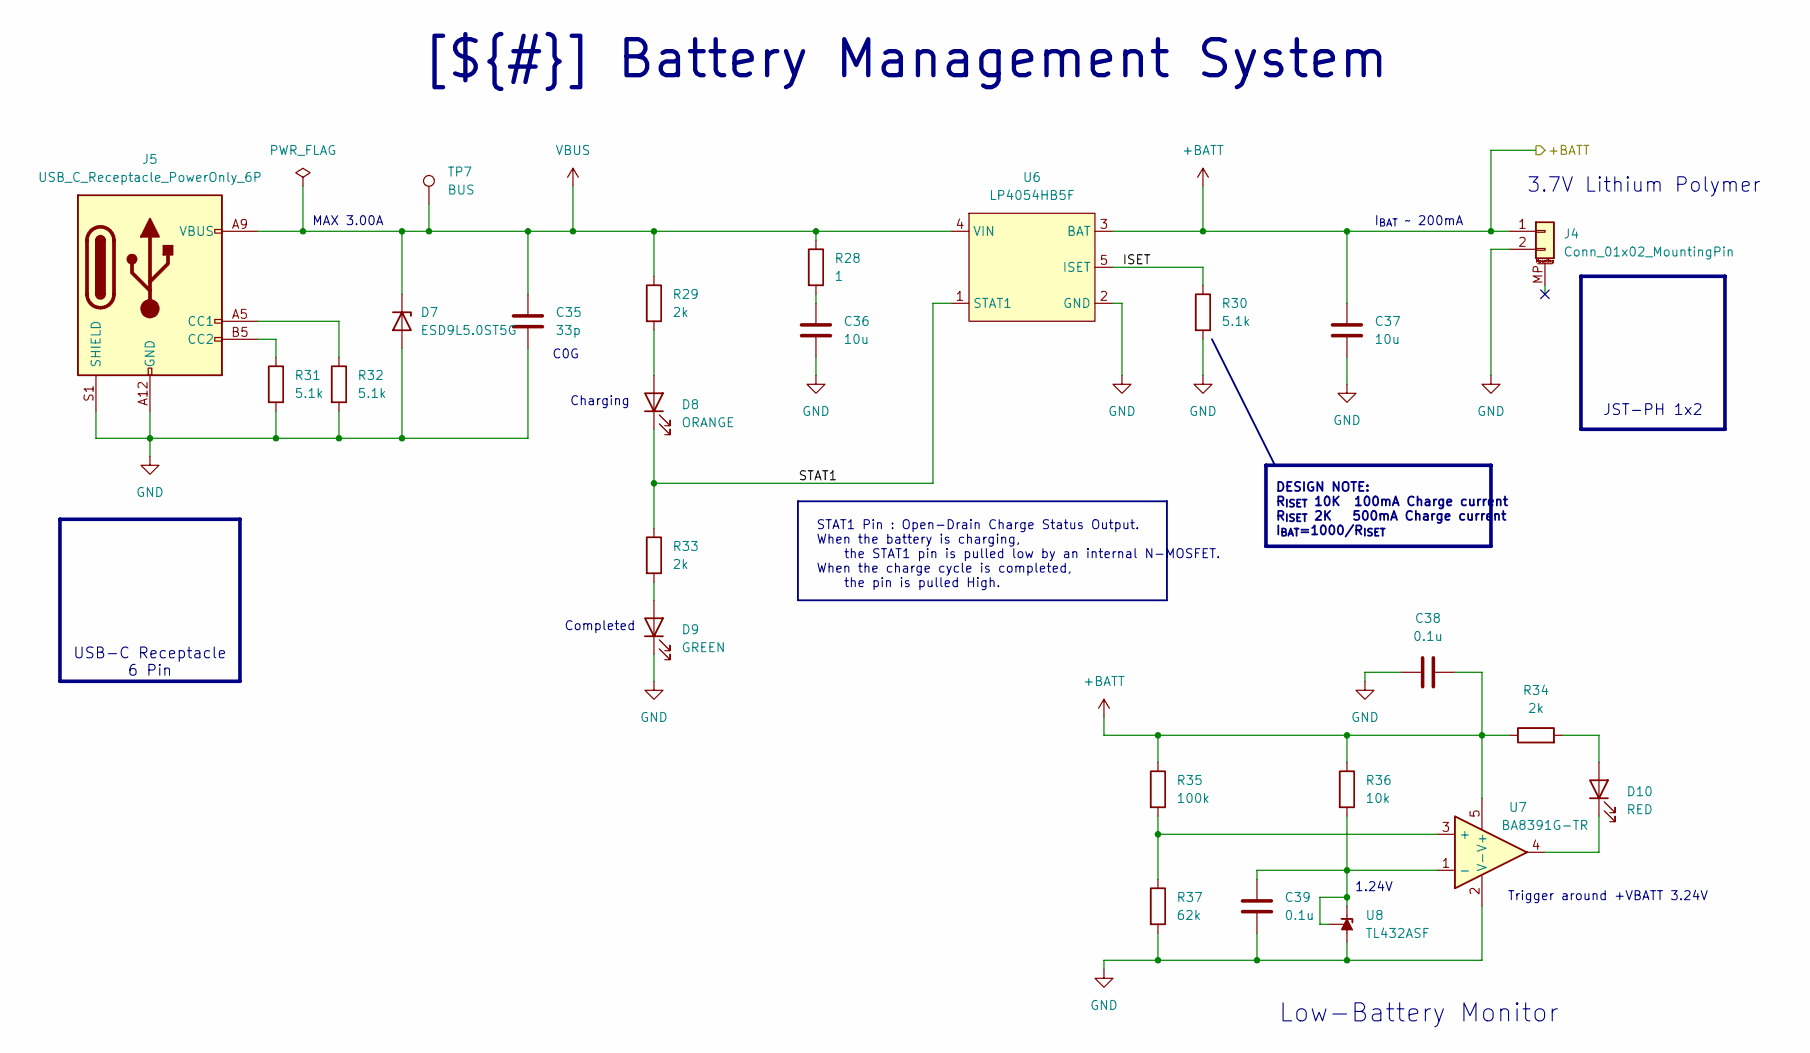
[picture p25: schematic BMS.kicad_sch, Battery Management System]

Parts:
C35: 33p; C_0402_1005Metric; Mf. Part Number 04025A330JAT2A
C36, C37: 10u; C_1206_3216Metric; Mf. Part Number CL31A106KBHNNNE
C38, C39: 0.1u; C_0402_1005Metric; Mf. Part Number GRM155R71H104KE14D
D7: ESD9L5.0ST5G; D_SOD-923_Edited; Mf. Part Number ESD9L5.0ST5G
D8: ORANGE; LED_0603_1608Metric; Mf. Part Number SML-D12D8WT86R
D9: GREEN; LED_0603_1608Metric; Mf. Part Number LTST-C191TGKT
D10: RED; LED_0603_1608Metric; Mf. Part Number LTST-C191KRKT
J4: Conn_01x02_MountingPin; JST_PH_S2B-PH-SM4-TB_1x02-1MP_P2.00mm_Horizontal; Mf. Part Number S2B-PH-SM4-TB
J5: USB_C_Receptacle_PowerOnly_6P; USB_C_Receptacle_GCT_USB4135-GF-A_6P_TopMnt_Horizontal; Mf. Part Number TYPEC6P019
R28: 1; R_0603_1608Metric; Mf. Part Number 0603WAF100KT5E
R29, R33, R34: 2k; R_0603_1608Metric; Mf. Part Number 0603WAF2001T5E
R30, R31, R32: 5.1k; R_0603_1608Metric; Mf. Part Number 0603WAF5101T5E
R35: 100k; R_0603_1608Metric; Mf. Part Number 0603WAF1003T5E
R36: 10k; R_0603_1608Metric; Mf. Part Number 0603WAF1002T5E
R37: 62k; R_0603_1608Metric; Mf. Part Number 0603WAF6202T5E
TP7: BUS; TestPoint_Pad_D1.0mm
U6: LP4054HB5F; SOT-23-5; Mf. Part Number LP4054H; LCSC Part C517187
U7: BA8391G-TR; SOT-23-5; Mf. Part Number BA8391G-TR
U8: TL432ASF; SOT-23; Mf. Part Number TL432ASF

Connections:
+BATT: C37.1, C38.1, J4.1, R34.1, R35.1, R36.1, U6.3 (BAT), U7.5 (V+); also elsewhere on the board
/Battery Management System/ISET: R30.1, U6.5 (ISET)
/Battery Management System/STAT1: D8.1 (K), R33.1, U6.1 (STAT1)
GND: C35.2, C36.2, C37.2, C38.2, C39.1, D7.2 (A), D9.1 (K), J4.2, J5.A12 (GND), J5.B12 (GND), J5.S1 (SHIELD), R30.2, R31.2, R32.2, R37.2, U6.2 (GND), U7.2 (V-), U8.3 (A); also elsewhere on the board
unnamed: C36.1, R28.2
unnamed: D8.2 (A), R29.2
unnamed: D9.2 (A), R33.2
unnamed: D10.2 (A), R34.2
unnamed: D10.1 (K), U7.4
unnamed: J5.A5 (CC1), R32.1
unnamed: J5.B5 (CC2), R31.1
unnamed: R35.2, R37.1, U7.3 (+)
unnamed: C39.2, R36.2, U7.1 (-), U8.1 (REF), U8.2 (K)
VBUS: C35.1, D7.1 (K), J5.A9 (VBUS), J5.B9 (VBUS), R28.1, R29.1, TP7.1, U6.4 (VIN)

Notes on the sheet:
3.7V Lithium Polymer
JST-PH 1x2
STAT1 Pin : Open-Drain Charge Status Output. When the battery is charging, the STAT1 pin is pulled low by an internal N-MOSFET. When the charge cycle is completed, the pin is pulled High.
C0G
USB-C Receptacle 6 Pin
Charging
1.24V
DESIGN NOTE: R_{ISET} 10K 100mA Charge current R_{ISET} 2K 500mA Charge current I_{BAT}=1000/R_{ISET}
Trigger around +VBATT 3.24V
MAX 3.00A
Low-Battery Monitor
I_{BAT} ~ 200mA
[${#}] ${TITLE}
Completed

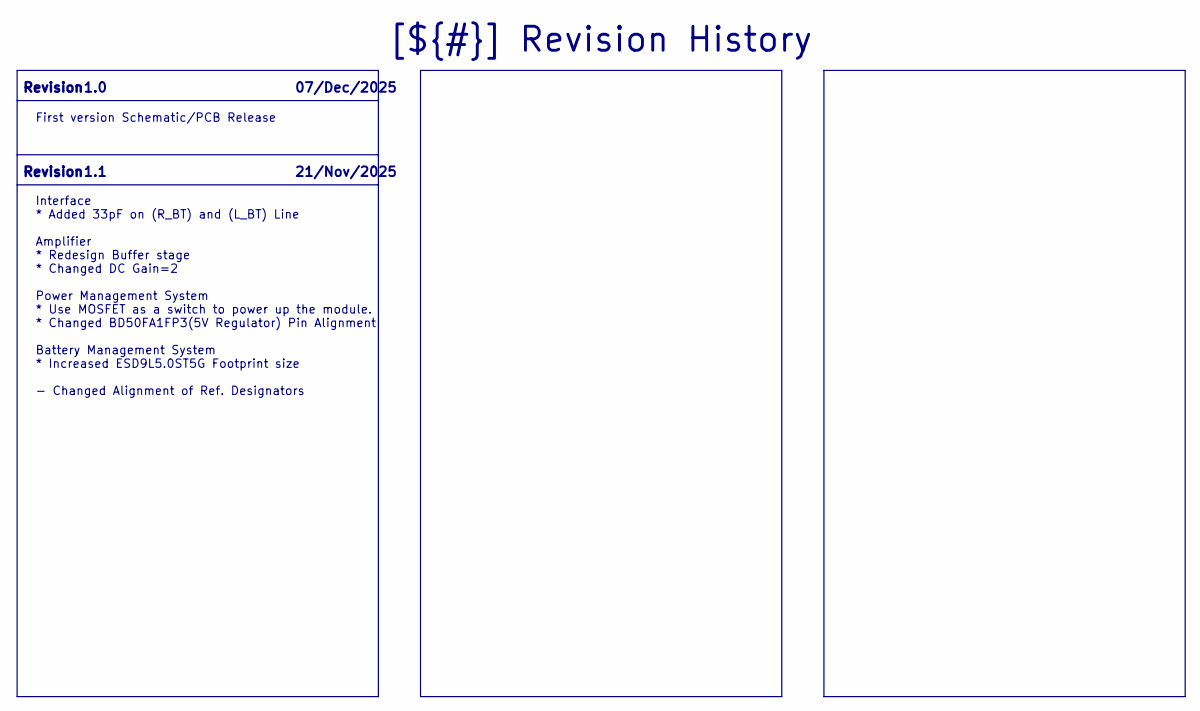
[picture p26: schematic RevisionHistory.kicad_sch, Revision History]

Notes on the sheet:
First version Schematic/PCB Release
Interface * Added 33pF on (R_BT) and (L_BT) Line Amplifier * Redesign Buffer stage * Changed DC Gain=2 Power Management System * Use MOSFET as a switch to power up the module. * Changed BD50FA1FP3(5V Regulator) Pin Alignment Battery Management System * Increased ESD9L5.0ST5G Footprint size - Change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
21/Nov/2025
07/Dec/2025
1.0
Revision
[${#}] ${TITLE}
1.1

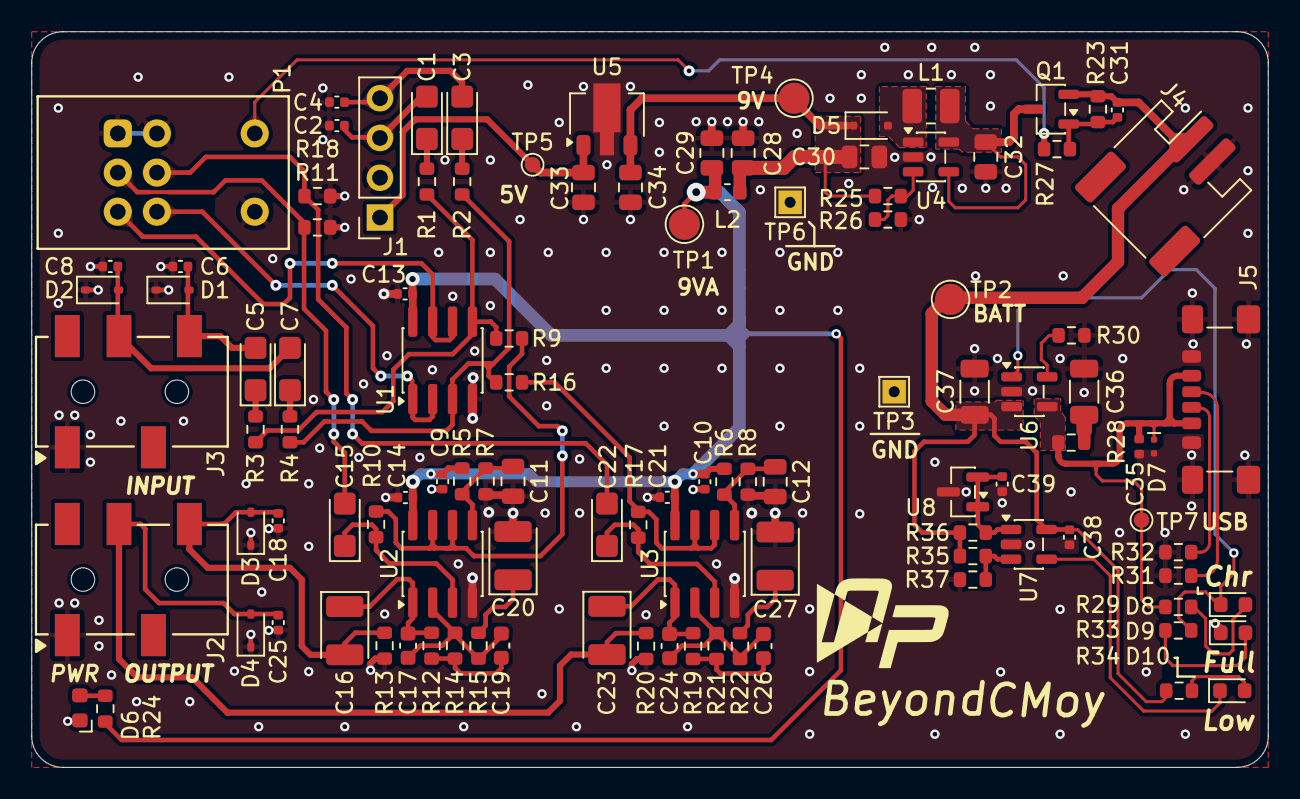
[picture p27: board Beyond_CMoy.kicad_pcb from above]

Board: 2 copper layers, 79.0 x 47.0 mm, 111 parts (0 on the bottom side), 53 nets.

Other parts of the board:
G1: LOGO

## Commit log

2025-11-30 Added project files
    [Amplifier.kicad_sch, BMS.kicad_sch, Beyond_CMoy.kicad_pcb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]
2025-11-30 Layout Board1
    [Amplifier.kicad_sch, Beyond_CMoy.kicad_pcb, Beyond_CMoy.kicad_sch]
2025-11-30 KiCAD do something
2025-12-01 PCB Layout
    [Beyond_CMoy.kicad_pcb]
2025-12-11 Update Doc and Same verison Release
    Release v1.0 , Update Doc Files
    [Amplifier.kicad_sch, BMS.kicad_sch, BOM 11-12-2025.xlsx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]
2025-12-11 Update BOM
    Edit Part Number but all the same
2025-12-18 Debugging & New Rev.
    [Amplifier.kicad_sch, BMS.kicad_sch, Beyond_CMoy.kicad_pcb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]
